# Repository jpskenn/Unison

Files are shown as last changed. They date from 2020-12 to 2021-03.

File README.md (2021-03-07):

# Unison / ユニゾン とは

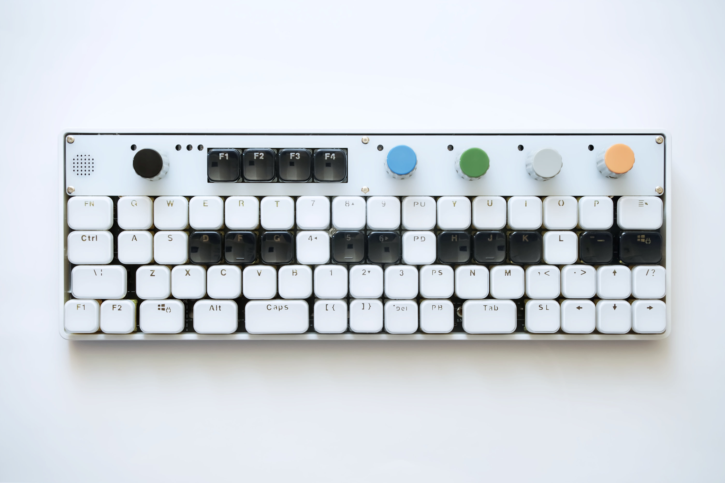
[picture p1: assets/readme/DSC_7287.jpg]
Unison Music style


ユニゾン（Unison）は、GH60互換の60%ケースに収まる狭ピッチキーボードです。  

ロータリーエンコーダを搭載しシーケンサーやMIDIキーボードとしてDAW連携を想定した”Misicスタイル（ミュージック・スタイル）”と、日常的なコンピュータ作業を想定した”Terminalスタイル（ターミナル・スタイル）”を用意しています。

音楽用とコンピュータ用のふたつのキーボードがひとつになるイメージから、音楽用語のユニゾンが名前の由来です。

## コンセプト

このキーボードのコンセプトや実現したい要件は次の通りです。

- 格好良いシンセサイザー、[OP-1](https://teenage.engineering/products/op-1)へのオマージュ。
- 狭ピッチなキーボードを作ってみたい。
- 狭ピッチなキーボードを使ってみたい。
- 挟ピッチなキーボードに触れる機会を増やしたい。
- ケースのあるキーボードを作りたいが、ケースの設計が大変だから、GH60型のケース対応にしてケース設計をメイン作業に含めない。
- キーキャップの選択肢を広げる。  
    安くて、そこそこ流通しているものが使えると普及しやすい。  
    標準的なキーキャプですべて埋められるレイアウトにしておく。
- 多キー、多ロータリーエンコーダ。

## 特徴

### 挟ピッチ

<!-- TODO　60%との比較写真  -->
<!-- TODO スイッチだけの写真 -->
通常の19.05mmのキーピッチに対して約87%となる、**縦16.4mm × 横16.8mm**のキーピッチを採用しています。

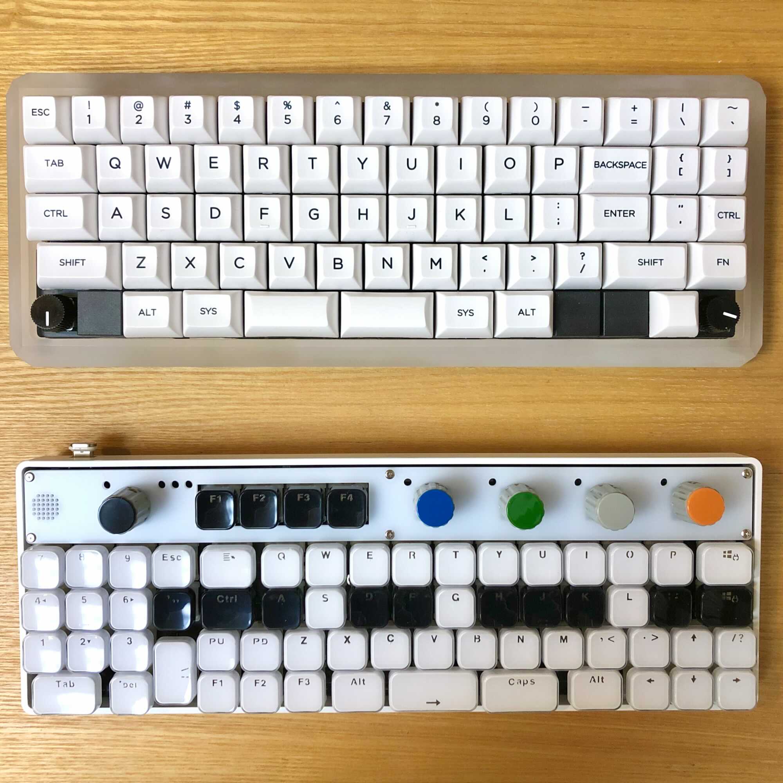
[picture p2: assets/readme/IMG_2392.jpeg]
通常のピッチの60%キーボードとの比較
  
通常のピッチの60%キーボードとの比較  
上：通常ピッチ Jones, 下：狭ピッチ Unison

デザインの元となったOP-1と同様に、4行×17列のキーとロータリーエンコーダが60%キーボードのケースに収まるように配置しました。  
また、キーピッチに少し余裕を持たせることで、入手性の良い”[Cherry MX Backlit Low Profile Keycap Set](https://yushakobo.jp/shop/cherry-mx-backlit-low-profile-keycap-set/)”が使用できるようにしています。

16mmピッチ＋α以下の挟ピッチ対応キーキャップが使用できます。  
挟ピッチ対応のキーキャップについては、e3w2q氏の記事”[狹ピッチ対応キーキャップを求めて](https://e3w2q.github.io/10/)”が大変参考になります。

<!-- TODO　ロープロキャップ写真 -->
<!-- TODO YKNキャップ写真 -->

### 独自の物理配列

以前設計した60%キーボードの[Jones](https://github.com/jpskenn/Jones)と同じく、2行目と3行目のずれをなくし、ロースタッガードとオルソリニアを組み合わせたキー配列を採用しています。  

アルファ部が左右対称になることで、肘、手首、指先が直線上に並んだ自然なポジションで打鍵できるなどのメリットがあります。  
詳しくは[Jones：キーレイアウト](https://github.com/jpskenn/Jones#キーレイアウト)を参照してください。

また、この配列を採用したことで、白鍵と黒鍵のずれをうまく表現できました。

### ふたつのレイアウト・スタイル

シーケンサーやMIDIキーボードとしてDAW連携を想定した”Misicスタイル”と、コンピュータでの作業を想定した”Terminalスタイル”の2種類が選べます。

#### Musicスタイル（ミュージック・スタイル）
<!-- TODO写真 -->

DAW連携を想定したMisicスタイルは、上部に5個のロータリーエンコーダと4個のスイッチを配置した、4行×17列のレイアウトです。

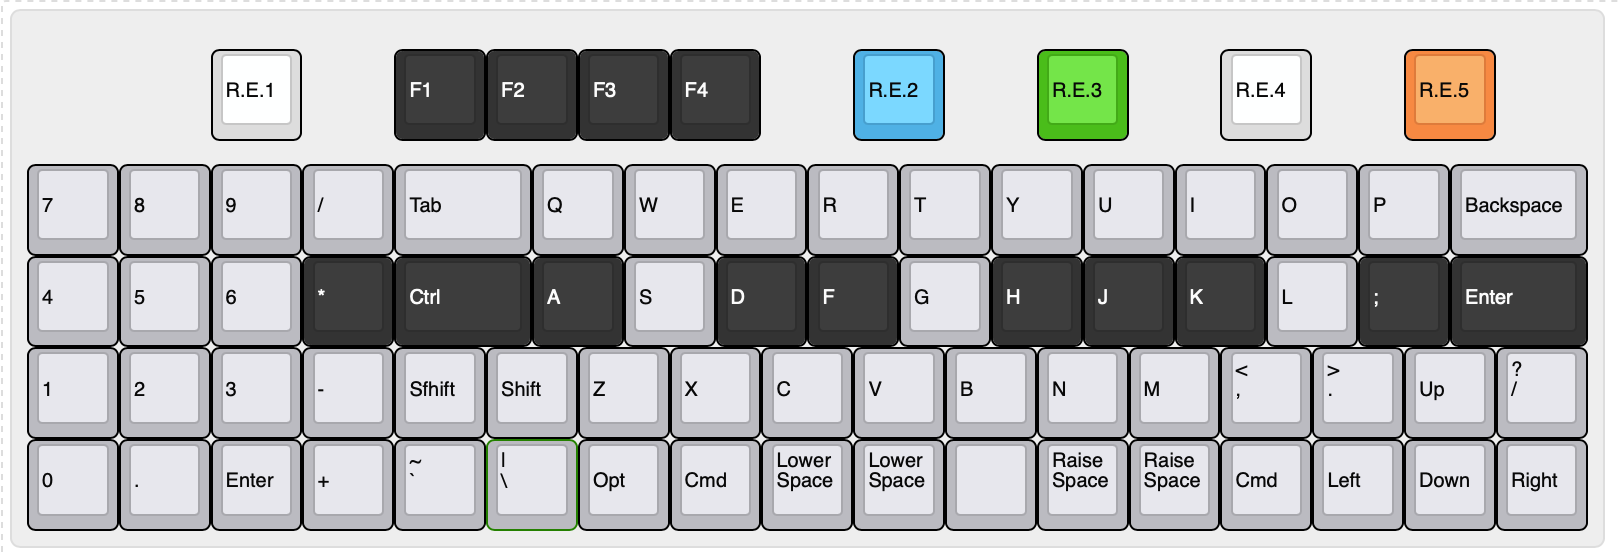
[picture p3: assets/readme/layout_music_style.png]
layout: Unison Music style
[Keyboard Layout Editor: Unison Music style](http://www.keyboard-layout-editor.com/#/gists/866c93c6eb4c580be0cf582207fa1836)

キーボードファームウェア[QMK](https://github.com/qmk/qmk_firmware)の機能によってシーケンサーとMIDIキーボードが使用でき、USB接続のMIDIデバイスとしてDAWと連携させることができます。  
もちろん、通常のコンピュータ用キーボードとしても使用できます。

シーケンサーは8トラック、32ステップあり、MIDIチャンネル1に固定されています。  
音源側（DAWなど）でチャンネル1にドラムセットを割り当てて使用するのが基本です。

MIDIキーボードは24鍵の鍵盤で演奏でき、ロータリーエンコーダを使ってベロシティやトランスポーズのコントロールやオクターブの上げ下げなどがおこなえます。

シーケンサーとMIDIキーボードは、それぞれ単独でも、両方を同時にでも使用できます。  
MIDIキーボードのチャンネルを変更することで、チャンネル1でシーケンサーを再生しながら、別チャンネルに割り当てた音源が演奏できます。

##### 参考

- シーケンサー操作ガイド
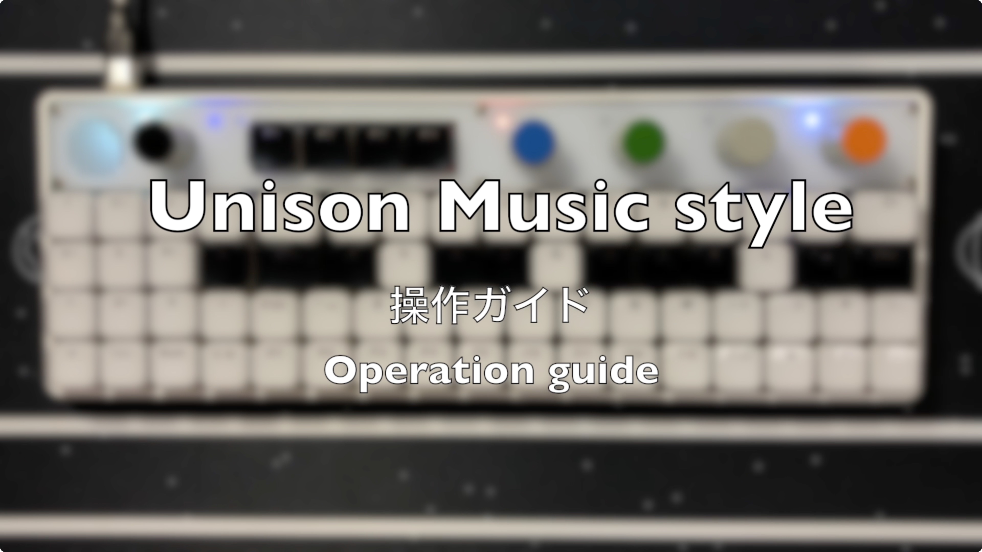
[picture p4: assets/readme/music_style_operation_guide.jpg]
Unison Music Style 操作ガイド / Operation guide (https://youtu.be/0ARp5gR2G88)
    
    [Unison Music Style 操作ガイド / Operation guide](https://youtu.be/0ARp5gR2G88)

- シーケンサーとMIDIキーボードを同時に使用するデモンストレーション  
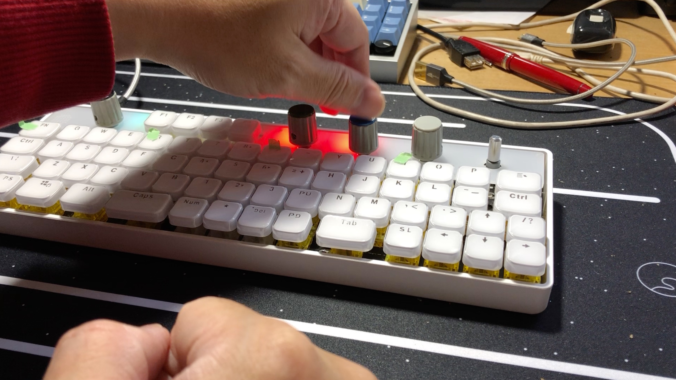
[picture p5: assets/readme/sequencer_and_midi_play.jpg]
QMK Sequencer & MIDI keyboard (http://www.youtube.com/watch?v=_A8NaXlWKeE "QMK Sequencer & MIDI keyboard")
      
    [QMK Sequencer & MIDI keyboard](http://www.youtube.com/watch?v=_A8NaXlWKeE)

#### Terminalスタイル（ターミナル・スタイル）
<!-- TODO写真 -->
コンピュータでの作業を想定したTerminalスタイルは、数字行を含めた5行×17列のレイアウトです。

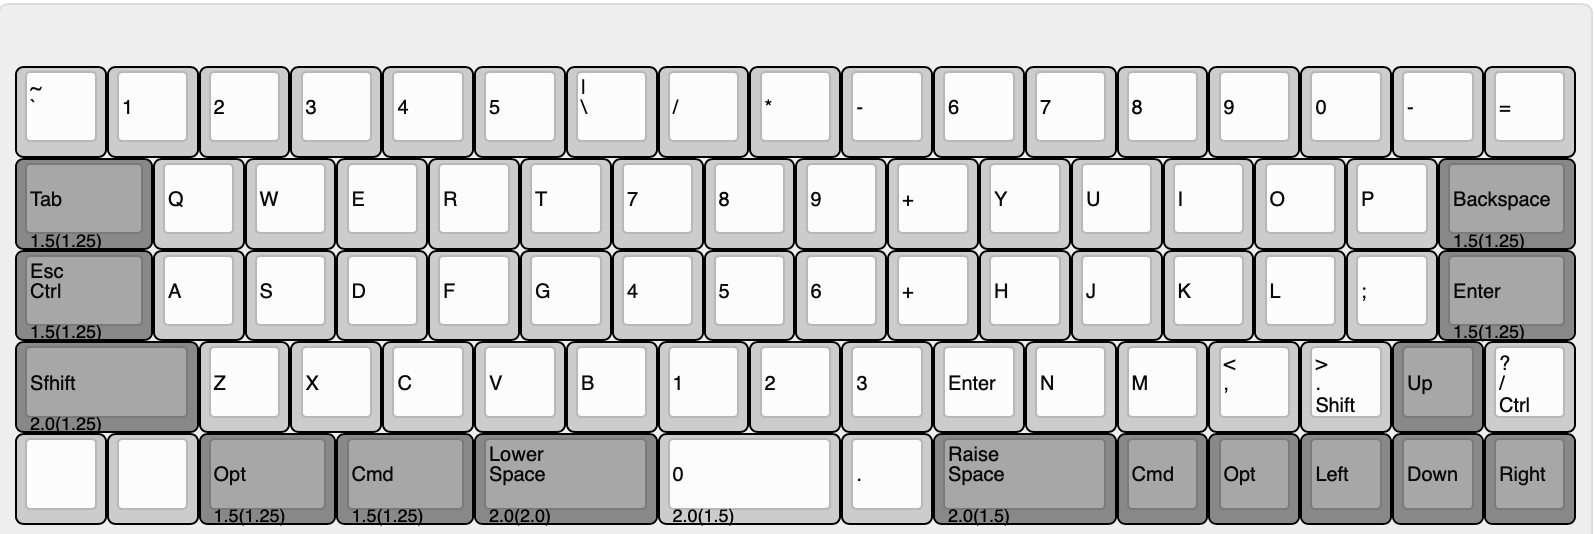
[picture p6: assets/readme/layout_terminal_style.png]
layout: Unison Music style
[Keyboard Layout Editor: Unison Terminal style](http://www.keyboard-layout-editor.com/#/gists/f8cf33730eca47e1e9039568cd3ca72c)

60%キーボードにテンキーを組み合わせたようなレイアウトで、挟ピッチによって手をホームポジションから大きく動かさずに入力することができ、コンピュータでの作業を快適におこなえます。  

最下行に配置した1.5uと2uのModキーの配置は、好みに応じていくつかのバリエーションから選択でき、全て1uにすることもできます。

テンキーは、肩を開いたホームポジションとなる中央への配置がおすすめですが、左や右に配置することもできます。  

また、スピーカーを搭載することで、特定のキー操作でメロディーを鳴らしたり、ピコピコという電子音とともにキー入力することもできます。  
音楽モードをONにすればキーボードを鍵盤に見立てて演奏することもでき、ちょっとしたハーモニーも楽しめます。

Terminalスタイルは、[VIA](https://caniusevia.com)または[Remap](https://remap-keys.app)によるキーマップの書き換えに対応しています。

## ビルドガイド

- [v04](https://github.com/jpskenn/Unison/blob/main/docs/BuildGuide_v04_JA.md)

## ギャラリー

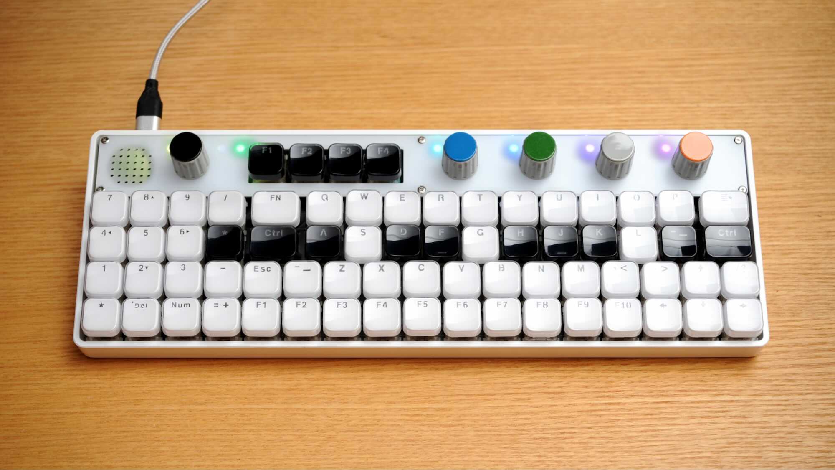
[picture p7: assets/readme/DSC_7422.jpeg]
Musicスタイル
  
Musicスタイル  
60% プラスチックケース ホワイト,  
Cherry MX Backlit Low Profile Keycap Set 白 & 黒,  
Bourns PEC11R 4115 w/K-100-16RS-GY and caps

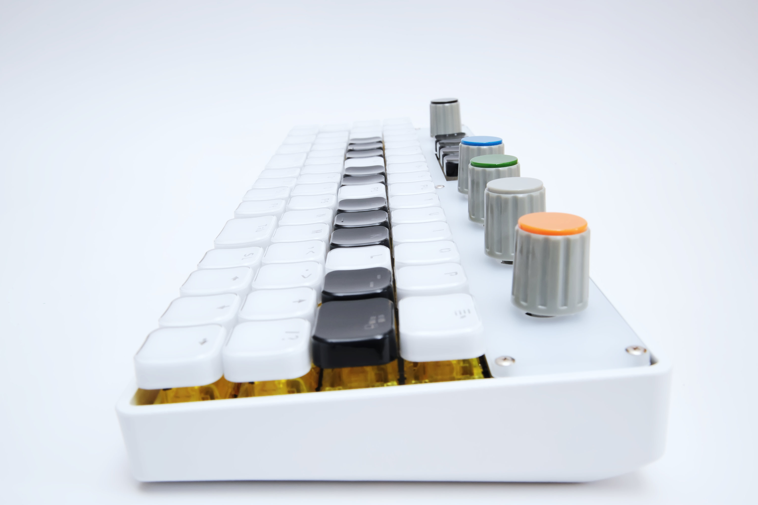
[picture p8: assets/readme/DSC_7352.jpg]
Musicスタイル, サイドビュー
  
Musicスタイル, サイドビュー  
60% プラスチックケース ホワイト,  
Cherry MX Backlit Low Profile Keycap Set 白 & 黒,  
EC11E18244AU w/K-100-16RS-GY and caps

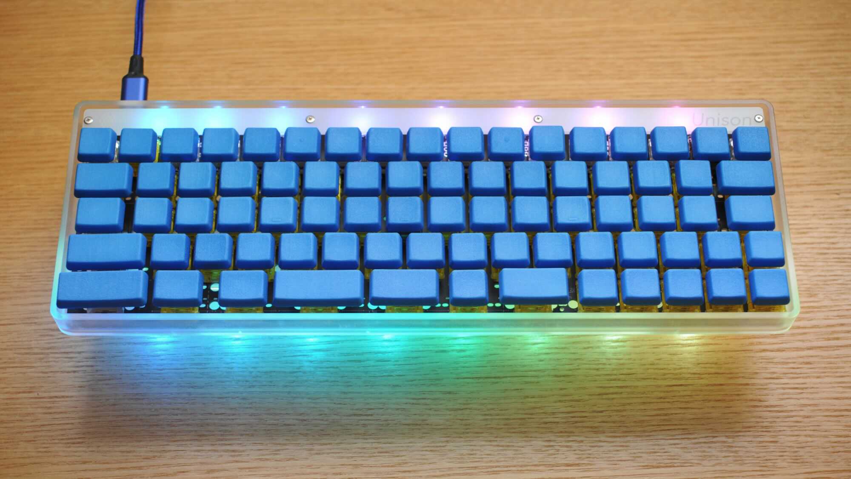
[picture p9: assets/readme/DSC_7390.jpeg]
  
Terminalスタイル, アンダーグローLED追加  
60% プラスチックケース クリア,  
YKNキーキャップセット(MX/ChocV2スイッチ 16x16mmキーピッチ用) v1.2 ナイロン・ブルー（磨き）

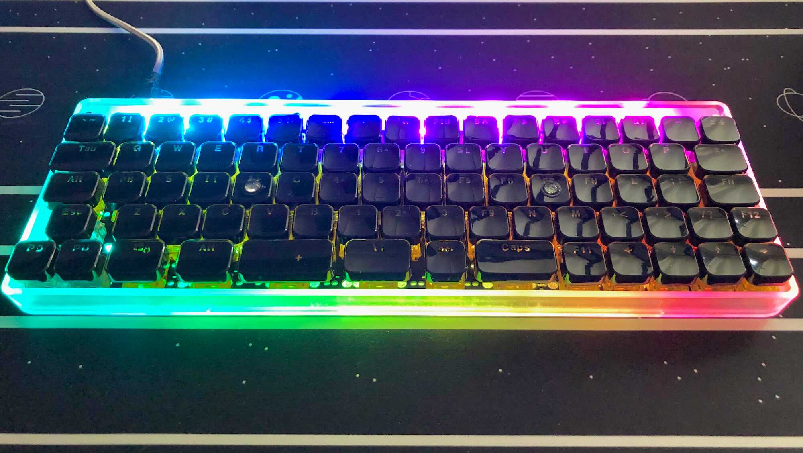
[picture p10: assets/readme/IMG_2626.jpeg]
  
Terminalスタイル, アンダーグローLED追加  
60% プラスチックケース クリア,  
Cherry MX Backlit Low Profile Keycap Set 黒

## 製作歴

### v05（開発中）

組み立てやすさの向上。  
細部の調整。

### v04

v03の不具合修正、各部調整などをおこなった、*ほぼ*完成版。  
ロータリーエンコーダを搭載せず、数字キーを含めた5行レイアウトのTerminalスタイルに対応。

簡易ケースレスなボトムプレートを用意したが、組み立てに難ありでボツ。

v04

### v03

初期動作版。

各部のサイズ調整をおこない、一通りの組み立てができ、動作も確認できた。  
キーピッチは縦16.4mm × 横16.8mmで確定。

LED光をマスクするミドルプレートや、アクリルのトッププレートも作成し、製品としての見た目もできあがってきた。  

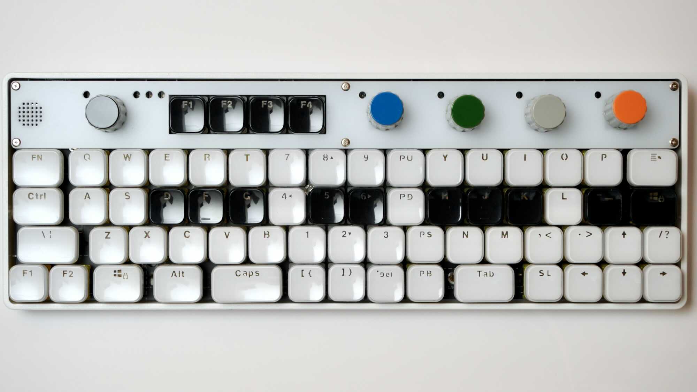
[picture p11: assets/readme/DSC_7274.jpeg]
v03


### v02

v01発注後、縦16mmピッチで基板データを仮に作成したもの。

キーピッチに余裕がないため、ボツ。

### v01

挟ピッチキーボードの試作として、Jonesの設計をベースに開発を開始。  
部品を手はんだするつもりで基板を発注したが、MCUのフットプリント間違いで組み立てられなかったたため、モックアップとして使用。

現在よりもピッチをつめた、5行×17列にロータリーエンコーダの1列を合わせたレイアウトで、縦のピッチは16mm未満。  
キーキャップの干渉具合や、ロータリーエンコーダの配置など、各部の寸法チェックをおこなった。

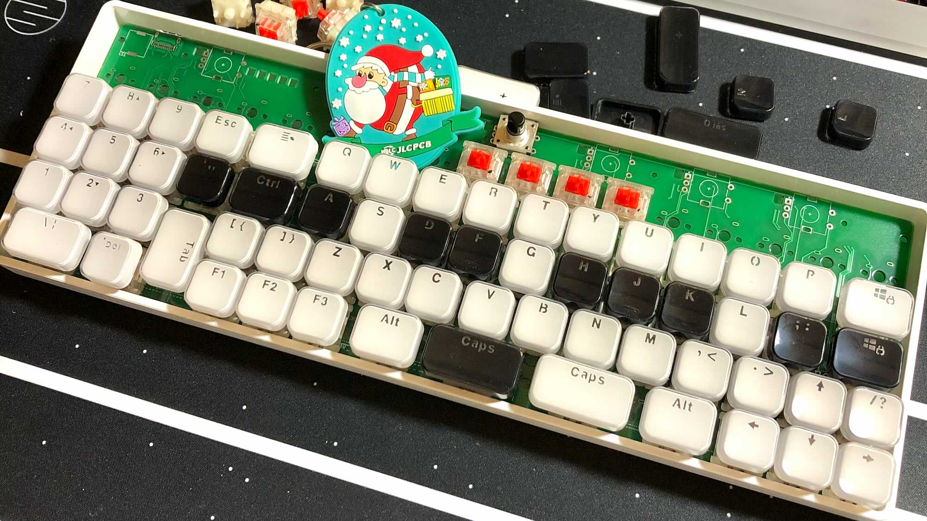
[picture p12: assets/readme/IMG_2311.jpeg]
v01


### v01以前

OP-1のスタイルに惚れ、60%キーボードの[Jones](https://github.com/jpskenn/Jones)に多数のロータリーエンコーダを搭載したバリエーションとして開発をスタート。

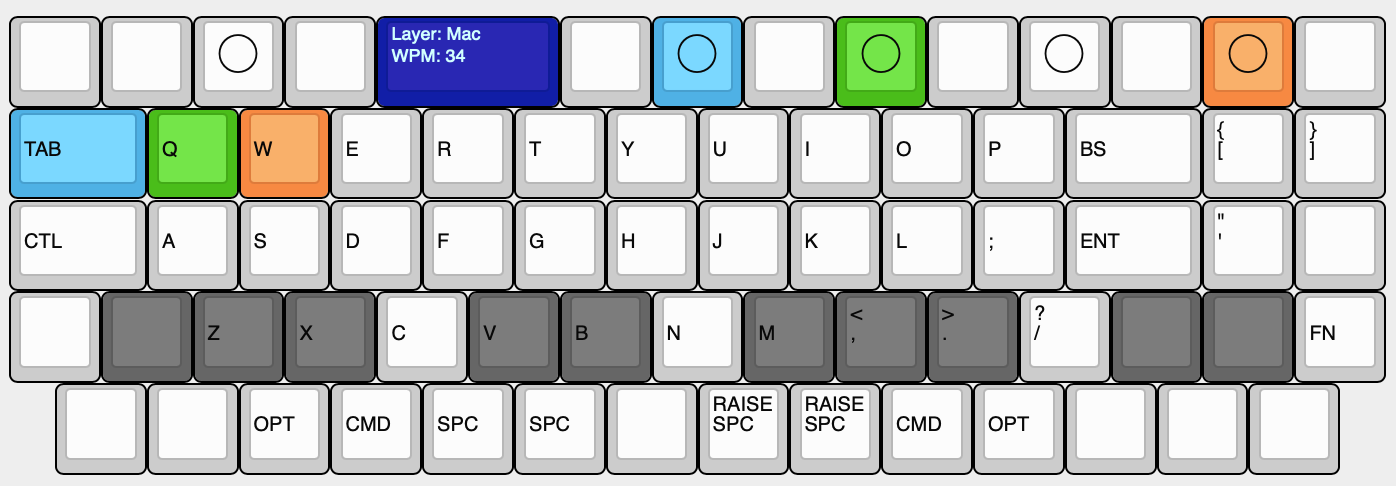
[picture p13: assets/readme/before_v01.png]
befre v01


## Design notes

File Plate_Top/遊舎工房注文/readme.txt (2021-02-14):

MacにてAffinity Designerを使いSVGファイルをを作成しました。
指定できる最小の線幅、0.1ptで作成しています。

A4サイズ内に、以下のパーツを配置しています。
285mm * 12.1mm　5個
285mm * 28.5mm　4個

同じ内容のPDFも用意しています。
緑（0, 255, 0)でA4の枠をつけてあります。

どちらか都合の良い方を使ってください。

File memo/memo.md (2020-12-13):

# Unisonについてのあれこれ

## サイズ、キー数

- Narrow pitch
    6 rows, 17 columns

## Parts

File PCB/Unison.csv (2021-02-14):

Comment | Designator | Footprint | LCSC
10uF | C1 | Capacitor_SMD:C_0805_2012Metric_Pad1.18x1.45mm_HandSolder | C15850
22pF | C2,C3 | Capacitor_SMD:C_0805_2012Metric_Pad1.18x1.45mm_HandSolder | C1804
0.1uF | C4,C5,C7 | Capacitor_SMD:C_0805_2012Metric_Pad1.18x1.45mm_HandSolder | C49678
1uF | C6 | Capacitor_SMD:C_0805_2012Metric_Pad1.18x1.45mm_HandSolder | C28323
PRTR5V0U2X | D102 | Package_TO_SOT_SMD:SOT-143
D | D1,D2,D3,D4,D5,D6,D7,D9,D10,D11,D12,D13,D14,D15,D16,D17,D18,D19,D20,D21,D22,D23,D24,D25,D26,D27,D28,D29,D30,D31,D32,D33,D34,D35,D36,D37,D38,D39,D40,D41,D42,D43,D44,D45,D46,D47,D48,D49,D50,D51,D52,D54,D55,D56,D57,D58,D59,D60,D61,D62,D63,D64,D66,D67,D68,D69,D70,D71,D72,D73,D74,D75,D76,D78,D79,D80,D81,D82,D83,D84,D85,D86,D87,D88,D90,D91,D92,D93,D94,D95,D96,D97,D98,D99 | Diode_SMD:D_SOD-123 | C81598
500mA | F1 | Fuse:Fuse_1206_3216Metric_Pad1.42x1.75mm_HandSolder
MountingHole | H1,H2,H3,H4,H5,H6,H7,H8,H9,H10,H11,H12,H13,H14,H15,H16,H17,H18 | ukiha:M2_Hole
USB4085-GF-A_REVA | J1 | USB4085:GCT_USB4085-GF-A_REVA
Conn_02x05[3_Odd_Even | J2 | Connector_PinHeader_2.54mm:PinHeader_2x03_P2.54mm_Vertical
LED Shade | J3 | Connector_PinSocket_2.54mm:PinSocket_1x03_P2.54mm_Vertical
Conn_01x02 | J4 | Connector_PinHeader_2.54mm:PinHeader_1x02_P2.54mm_Vertical
SolderJumper_3_Open | JP_LED1,JP_LED2 | Jumper:SolderJumper-3_P1.3mm_Open_Pad1.0x1.5mm_NumberLabels
SK6812MINI | L1,L2,L3,L4,L5,L6,L7,L8,L9 | LED_SMD:LED_SK6812MINI_PLCC4_3.5x3.5mm_P1.75mm
SERIAL_LED_TAPE | L15 | ukiha:StripLED_rev3
Speaker | LS1 | Buzzer_Beeper:Buzzer_Murata_PKMCS0909E4000-R1
1k | R1 | Resistor_SMD:R_0805_2012Metric_Pad1.20x1.40mm_HandSolder | C17513
10k | R4,R9 | Resistor_SMD:R_0805_2012Metric_Pad1.20x1.40mm_HandSolder | C17414
5.1k | R5,R6 | Resistor_SMD:R_0805_2012Metric_Pad1.20x1.40mm_HandSolder | C27834
22 | R7,R8 | Resistor_SMD:R_0805_2012Metric_Pad1.20x1.40mm_HandSolder | C17561
5.2x5.2mm | ResetSW1 | Button_Switch_SMD:SW_SPST_SKQG_WithStem
SW_Push | SW_21,SW_53,SW_8_1,SW_91,SW_18_1 | ukiha:MXOnly-1U-NoLED_16mm
SW_Push | SW_25_2,SW_60_2,SW_90_2 | ukiha:CherryMX_MidHeight_16mm_rev2_merged_hole_2U_vertical_guide
SW_Push | SW_6,SW_9,SW_14,SW_15,SW_16,SW_26,SW_29,SW_31,SW_34,SW_42,SW_43,SW_47,SW_48,SW_49,SW_50,SW_52,SW_54,SW_56,SW_57,SW_58,SW_59,SW_61,SW_62,SW_63,SW_64,SW_67,SW_68,SW_69,SW_71,SW_7_1,SW_74,SW_76,SW_79,SW_81,SW_84,SW_86,SW_89,SW_94,SW_95,SW_96,SW_10_1,SW_12_1,SW_12_2,SW_13_1,SW_13_2,SW_17_1,SW_19_1,SW_20_1,SW_23_1,SW_23_2,SW_24_1,SW_25_1,SW_27_1,SW_27_2,SW_28_1,SW_28_2,SW_30_1,SW_32_1,SW_32_2,SW_36_1,SW_36_2,SW_37_1,SW_38_1,SW_39_1,SW_40_1,SW_41_1,SW_41_2,SW_46_1,SW_46_2,SW_51_1,SW_51_2,SW_60_1,SW_70_1,SW_72_1,SW_73_1,SW_78_1,SW_78_2,SW_80_1,SW_82_1,SW_82_2,SW_83_1,SW_83_2,SW_85_1,SW_87_1,SW_87_2,SW_90_1,SW_97_1,SW_97_2,SW_98_1,SW_98_2 | ukiha:CherryMX_MidHeight_16mm_rev2_merged_hole
SW_Push | SW_10_2,SW_19_2,SW_35_1,SW_35_2,SW_39_2,SW_45_1,SW_45_2,SW_65_1,SW_75_3,SW_85_2 | ukiha:CherryMX_MidHeight_16mm_rev2_merged_hole_2u_guide
SW_Push | SW_37_2 | ukiha:CherryMX_MidHeight_16mm_rev2_merged_hole_1.5u_alt_guide
SW_Push | SW_60_3,SW_75_1 | ukiha:MXOnly-2U-NoLED_16mm
SW_Push | SW_75_2 | ukiha:MXOnly-1.5U-NoLED_16mm
SW_Push | SW_7_2,SW_8_2,SW_17_2,SW_18_2,SW_20_2,SW_25_3,SW_30_2,SW_35_3,SW_38_2,SW_45_3,SW_45_4,SW_65_2,SW_65_3,SW_70_2,SW_72_2,SW_73_2,SW_80_2,SW_85_3 | ukiha:CherryMX_MidHeight_16mm_rev2_merged_hole_1.5u_guide
Rotary_Encoder_Switch | SW_RE1,SW_RE2,SW_RE3,SW_RE4,SW_RE5 | ukiha:RotaryEncoder_Alps_EC11K-Switch_Vertical_H20mm
ATmega32U4-MU | U1 | swanmatch:QFN-44-1EP_7x7mm_Pitch0.5mm | C45874
16MHz | Y1 | Crystal:Crystal_SMD_3225-4Pin_3.2x2.5mm_HandSoldering | C13738

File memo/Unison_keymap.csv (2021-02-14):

XXXXXXX | XXXXXXX |  | KC_MUTE |  | XXXXXXX |  | KC_1 |  | KC_2 |  | KC_3 |  | KC_4 |  | XXXXXXX |  | KC_MUTE |  | XXXXXXX |  | KC_MUTE |  | XXXXXXX |  | KC_MUTE |  | XXXXXXX |  | KC_MUTE |  | XXXXXXX
KC_TAB |  | KC_Q |  | KC_W |  | KC_E |  | KC_R |  | KC_T |  | ESC |  | KC_PSLS |  | KC_PAST |  | KC_PMNS |  | KC_Y |  | KC_U |  | KC_I |  | KC_O |  | KC_P |  | KC_BSPC
KC_LCTL |  | KC_A |  | KC_S |  | KC_D |  | KC_F |  | KC_G |  | KC_P7 |  | KC_P8 |  | KC_P9 |  | KC_PPLS |  | KC_H |  | KC_J |  | KC_K |  | KC_L |  | KC_MINS |  | KC_ENT
KC_LSFT | KC_LSFT |  | KC_Z |  | KC_X |  | KC_C |  | KC_V |  | KC_B |  | KC_P1 |  | KC_P2 |  | KC_P3 |  | KC_PENT |  | KC_N |  | KC_M |  | KC_COMM |  | KC_DOT |  | KC_UP |  | SFT_SLS
KC_CAPS | KC_CAPS |  | OPT_L2 |  | XXXXXXX |  | CMD_L1 |  | SP_LOW |  | SP_LOW |  | KC_P0 |  | KC_P0 |  | KC_PDOT |  | SP_RAI |  | SP_RAI |  | SP_RAI |  | KC_RCTL |  | KC_LEFT |  | KC_DOWN |  | KC_RGHT
XXXXXXX | XXXXXXX |  | _______ |  | XXXXXXX |  | _______ |  | _______ |  | _______ |  | _______ |  | XXXXXXX |  | _______ |  | XXXXXXX |  | _______ |  | XXXXXXX |  | _______ |  | XXXXXXX |  | _______ |  | XXXXXXX
ESC |  | ! |  | @ |  | # |  | $ |  | % |  | _______ |  | _______ |  | _______ |  | _______ |  | ^ |  | & |  | * |  | ( |  | ) |  | DEL
_______ |  | _______ |  | _______ |  | _______ |  | _______ |  | _______ |  | _______ |  | _______ |  | _______ |  | _______ |  | `~ |  | -_ |  | =+ |  | [{ |  | ]} |  | \
_______ | _______ |  | M_PSCR |  | KC_SLCK |  | KC_PAUS |  | _______ |  | _______ |  | _______ |  | _______ |  | _______ |  | _______ |  | ~ |  | _ |  | + |  | { |  | }
_______ | _______ |  | MENU |  | XXXXXXX |  | _______ |  | _______ |  | _______ |  | _______ |  | _______ |  | _______ |  | _______ |  | _______ |  | _______ |  | _______ |  | _______ |  | _______ |  | _______
 |  |  | *MENU don't work on Mac
XXXXXXX | XXXXXXX |  | _______ |  | XXXXXXX |  | _______ |  | _______ |  | _______ |  | _______ |  | XXXXXXX |  | _______ |  | XXXXXXX |  | _______ |  | XXXXXXX |  | _______ |  | XXXXXXX |  | _______ |  | XXXXXXX
ESC |  | 1 |  | 2 |  | 3 |  | 4 |  | 5 |  | _______ |  | _______ |  | _______ |  | _______ |  | 6 |  | 7 |  | 8 |  | 9 |  | 0 |  | DEL
_______ |  | F1 |  | F2 |  | F3 |  | F4 |  | F5 |  | _______ |  | _______ |  | _______ |  | _______ |  | ← |  | ↓ |  | ↑ |  | → |  | ;: |  | '"
_______ | _______ |  | F6 |  | F7 |  | F8 |  | F9 |  | F10 |  | _______ |  | _______ |  | _______ |  | _______ |  | Home |  | PgDn |  | PgUp |  | End |  | : |  | "
_______ | _______ |  | F11 |  | XXXXXXX |  | F12 |  | _______ |  | _______ |  | _______ |  | _______ |  | _______ |  | _______ |  | _______ |  | _______ |  | ESC |  | _______ |  | _______ |  | _______
XXXXXXX | XXXXXXX |  | _______ |  | XXXXXXX |  | _______ |  | _______ |  | _______ |  | _______ |  | XXXXXXX |  | _______ |  | XXXXXXX |  | _______ |  | XXXXXXX |  | _______ |  | XXXXXXX |  | _______ |  | XXXXXXX
_______ |  | MAC |  | WIN |  | MIDI |  | RESET |  | _______ |  | _______ |  | _______ |  | _______ |  | _______ |  | RGB_HUI |  | RGB_SAI |  | RBG_VAI |  | _______ |  | RGB_RMOD |  | _______
_______ |  | AU_TOG |  | CK_TOGG |  | MU_TOG |  | MU_MOD |  | _______ |  | _______ |  | _______ |  | _______ |  | _______ |  | RBG_HUD |  | RBG_SAD |  | RBG_VAD |  | RGB_TOG |  | RGB_MOD |  | _______
_______ | _______ |  | CK_RST |  | CK_DOWN |  | CK_UP |  | _______ |  | _______ |  | _______ |  | _______ |  | _______ |  | _______ |  | _______ |  | _______ |  | _______ |  | _______ |  | _______ |  | _______
_______ | _______ |  | _______ |  | XXXXXXX |  | _______ |  | _______ |  | _______ |  | _______ |  | _______ |  | _______ |  | _______ |  | _______ |  | _______ |  | _______ |  | _______ |  | _______ |  | _______

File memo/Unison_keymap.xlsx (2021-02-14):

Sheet: Sheet1
MAC
 | XXXXXXX | XXXXXXX | KC_MUTE | XXXXXXX | KC_P1 | KC_P2 | KC_P3 | KC_P4 | XXXXXXX | KC_MUTE | XXXXXXX | KC_MUTE | XXXXXXX | KC_MUTE | XXXXXXX | KC_MUTE | XXXXXXX
 | KC_TAB |  | KC_Q | KC_W | KC_E | KC_R | KC_T | KC_LBRC | KC_GRV | KC_BSLS | KC_RBRC | KC_Y | KC_U | KC_I | KC_O | KC_P | KC_BSPC
 | KC_LCTL |  | KC_A | KC_S | KC_D | KC_F | KC_G | KC_SCLN | KC_NLCK | KC_ESC | KC_QUOT | KC_H | KC_J | KC_K | KC_L | KC_MINS | KC_ENT
 | KC_LSFT | KC_LSFT | KC_Z | KC_X | KC_C | KC_V | KC_B | M_PSCR | KC_INS | KC_HOME | XXXXXXX | KC_N | KC_M | KC_COMM | KC_DOT | KC_UP | SFT_SLS
 | KC_CAPS | KC_CAPS | KC_LALT | XXXXXXX | KC_LGUI | SP_LOW | SP_LOW | KC_P0 | KC_DEL | KC_END | KC_PENT | SP_RAI | SP_RAI | KC_RCTL | KC_LEFT | KC_DOWN | KC_RGHT
LOWER
 | XXXXXXX |  | _______ | _______ | XXXXXXX | _______ | _______ | _______ | _______ | XXXXXXX | _______ | XXXXXXX | _______ | XXXXXXX | _______ | XXXXXXX | _______ | XXXXXXX
 | KC_1 |  | KC_2 | KC_3 | KC_4 | KC_5 | KC_6 | _______ | _______ | _______ | _______ | KC_7 | KC_8 | KC_9 | KC_0 | KC_MINS | KC_EQL
 | KC_F1 |  | KC_F2 | KC_F3 | KC_F4 | KC_F5 | KC_F6 | _______ | _______ | _______ | _______ | KC_F7 | KC_F8 | KC_F9 | KC_F10 | KC_F11 | KC_F12
 | _______ |  | _______ | _______ | _______ | _______ | _______ | _______ | _______ | _______ | _______ | _______ | _______ | _______ | KC_LBRC | KC_RBRC | KC_PGUP | _______
 | _______ |  | _______ | _______ | _______ | _______ | _______ | _______ | _______ | _______ | _______ | _______ | _______ | _______ | _______ | KC_HOME | KC_PGDN | KC_END
RAISE
 | XXXXXXX |  | _______ | _______ | XXXXXXX | _______ | _______ | _______ | _______ | XXXXXXX | _______ | XXXXXXX | _______ | XXXXXXX | _______ | XXXXXXX | _______ | XXXXXXX
 | KC_EXLM |  | KC_AT | KC_HASH | KC_DLR | KC_PERC | KC_CIRC | _______ | _______ | _______ | _______ | KC_AMPR | KC_ASTR | KC_LPRN | KC_RPRN | KC_UNDS | KC_PLUS
 | _______ |  | _______ | _______ | _______ | _______ | KC_ESC | _______ | _______ | _______ | _______ | KC_LEFT | KC_DOWN | KC_UP | KC_RGHT | KC_SCLN | KC_DEL
 | _______ |  | _______ | _______ | _______ | _______ | _______ | _______ | _______ | _______ | _______ | _______ | _______ | _______ | KC_LCBR | KC_RCBR | KC_PGUP | _______
 | _______ |  | _______ | _______ | _______ | _______ | _______ | _______ | _______ | _______ | _______ | _______ | _______ | _______ | _______ | KC_HOME | KC_PGDN | KC_END
ADJUST
 | XXXXXXX |  | _______ | _______ | XXXXXXX | _______ | _______ | _______ | _______ | XXXXXXX | _______ | XXXXXXX | _______ | XXXXXXX | _______ | XXXXXXX | _______ | XXXXXXX
 | _______ |  | MIDI | WIN | _______ | RESET | _______ | _______ | _______ | _______ | _______ | RGB_HUI | RGB_SAI | RGB_VAI | _______ | RGB_RMOD | _______
 | _______ |  | _______ | _______ | _______ | _______ | _______ | _______ | _______ | _______ | _______ | RGB_HUD | RGB_SAD | RGB_VAD | RGB_TOG | RGB_MOD | _______
 | _______ |  | _______ | _______ | _______ | _______ | _______ | _______ | _______ | _______ | _______ | _______ | NUM | MAC | _______ | _______ | _______ | _______
 | _______ |  | _______ | _______ | _______ | _______ | _______ | _______ | _______ | _______ | _______ | _______ | _______ | _______ | _______ | _______ | _______ | _______

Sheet: Sheet1 (2)
MAC
 | XXXXXXX | XXXXXXX | KC_MUTE | XXXXXXX | KC_P1 | KC_P2 | KC_P3 | KC_P4 | XXXXXXX | KC_MUTE | XXXXXXX | KC_MUTE | XXXXXXX | KC_MUTE | XXXXXXX | KC_MUTE | XXXXXXX
 | KC_TAB |  | KC_Q | KC_W | KC_E | KC_R | KC_T | KC_LBRC | KC_GRV | KC_BSLS | KC_RBRC | KC_Y | KC_U | KC_I | KC_O | KC_P | KC_BSPC
 | KC_LCTL |  | KC_A | KC_S | KC_D | KC_F | KC_G | KC_SCLN | KC_NLCK | KC_ESC | KC_QUOT | KC_H | KC_J | KC_K | KC_L | KC_MINS | KC_ENT
 | KC_LSFT | KC_LSFT | KC_Z | KC_X | KC_C | KC_V | KC_B | M_PSCR | KC_INS | KC_HOME | XXXXXXX | KC_N | KC_M | KC_COMM | KC_DOT | KC_UP | SFT_SLS
 | KC_CAPS | KC_CAPS | KC_LALT | XXXXXXX | KC_LGUI | SP_LOW | SP_LOW | KC_P0 | KC_DEL | KC_END | KC_PENT | SP_RAI | SP_RAI | KC_RCTL | KC_LEFT | KC_DOWN | KC_RGHT
LOWER
 | XXXXXXX |  | _______ | _______ | XXXXXXX | _______ | _______ | _______ | _______ | XXXXXXX | _______ | XXXXXXX | _______ | XXXXXXX | _______ | XXXXXXX | _______ | XXXXXXX
 | KC_1 |  | KC_2 | KC_3 | KC_4 | KC_5 | KC_6 | _______ | _______ | _______ | _______ | KC_7 | KC_8 | KC_9 | KC_0 | KC_MINS | KC_EQL
 | KC_F1 |  | KC_F2 | KC_F3 | KC_F4 | KC_F5 | KC_F6 | _______ | _______ | _______ | _______ | KC_F7 | KC_F8 | KC_F9 | KC_F10 | KC_F11 | KC_F12
 | _______ |  | _______ | _______ | _______ | _______ | _______ | _______ | _______ | _______ | _______ | _______ | _______ | _______ | KC_LBRC | KC_RBRC | KC_PGUP | _______
 | _______ |  | _______ | _______ | _______ | _______ | _______ | _______ | _______ | _______ | _______ | _______ | _______ | _______ | _______ | KC_HOME | KC_PGDN | KC_END
RAISE
 | XXXXXXX |  | _______ | _______ | XXXXXXX | _______ | _______ | _______ | _______ | XXXXXXX | _______ | XXXXXXX | _______ | XXXXXXX | _______ | XXXXXXX | _______ | XXXXXXX
 | KC_EXLM |  | KC_AT | KC_HASH | KC_DLR | KC_PERC | KC_CIRC | _______ | _______ | _______ | _______ | KC_AMPR | KC_ASTR | KC_LPRN | KC_RPRN | KC_UNDS | KC_PLUS
 | _______ |  | _______ | _______ | _______ | _______ | KC_ESC | _______ | _______ | _______ | _______ | KC_LEFT | KC_DOWN | KC_UP | KC_RGHT | KC_SCLN | KC_DEL
 | _______ |  | _______ | _______ | _______ | _______ | _______ | _______ | _______ | _______ | _______ | _______ | _______ | _______ | KC_LCBR | KC_RCBR | KC_PGUP | _______
 | _______ |  | _______ | _______ | _______ | _______ | _______ | _______ | _______ | _______ | _______ | _______ | _______ | _______ | _______ | KC_HOME | KC_PGDN | KC_END
ADJUST
 | XXXXXXX |  | _______ | _______ | XXXXXXX | _______ | _______ | _______ | _______ | XXXXXXX | _______ | XXXXXXX | _______ | XXXXXXX | _______ | XXXXXXX | _______ | XXXXXXX
 | _______ |  | MIDI | WIN | _______ | RESET | _______ | _______ | _______ | _______ | _______ | RGB_HUI | RGB_SAI | RGB_VAI | _______ | RGB_RMOD | _______
 | _______ |  | _______ | _______ | _______ | _______ | _______ | _______ | _______ | _______ | _______ | RGB_HUD | RGB_SAD | RGB_VAD | RGB_TOG | RGB_MOD | _______
 | _______ |  | _______ | _______ | _______ | _______ | _______ | _______ | _______ | _______ | _______ | _______ | NUM | MAC | _______ | _______ | _______ | _______
 | _______ |  | _______ | _______ | _______ | _______ | _______ | _______ | _______ | _______ | _______ | _______ | _______ | _______ | _______ | _______ | _______ | _______

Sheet: Sheet3
XXXXXXX | XXXXXXX |  | KC_MUTE |  | XXXXXXX |  | KC_1 |  | KC_2 |  | KC_3 |  | KC_4 |  | XXXXXXX |  | KC_MUTE |  | XXXXXXX |  | KC_MUTE |  | XXXXXXX |  | KC_MUTE |  | XXXXXXX |  | KC_MUTE |  | XXXXXXX
KC_TAB |  | KC_Q |  | KC_W |  | KC_E |  | KC_R |  | KC_T |  | ESC |  | KC_PSLS |  | KC_PAST |  | KC_PMNS |  | KC_Y |  | KC_U |  | KC_I |  | KC_O |  | KC_P |  | KC_BSPC
KC_LCTL |  | KC_A |  | KC_S |  | KC_D |  | KC_F |  | KC_G |  | KC_P7 |  | KC_P8 |  | KC_P9 |  | KC_PPLS |  | KC_H |  | KC_J |  | KC_K |  | KC_L |  | KC_MINS |  | KC_ENT
KC_LSFT | KC_LSFT |  | KC_Z |  | KC_X |  | KC_C |  | KC_V |  | KC_B |  | KC_P1 |  | KC_P2 |  | KC_P3 |  | KC_PENT |  | KC_N |  | KC_M |  | KC_COMM |  | KC_DOT |  | KC_UP |  | SFT_SLS
KC_CAPS | KC_CAPS |  | OPT_L2 |  | XXXXXXX |  | CMD_L1 |  | SP_LOW |  | SP_LOW |  | KC_P0 |  | KC_P0 |  | KC_PDOT |  | SP_RAI |  | SP_RAI |  | SP_RAI |  | KC_RCTL |  | KC_LEFT |  | KC_DOWN |  | KC_RGHT
XXXXXXX | XXXXXXX |  | _______ |  | XXXXXXX |  | _______ |  | _______ |  | _______ |  | _______ |  | XXXXXXX |  | _______ |  | XXXXXXX |  | _______ |  | XXXXXXX |  | _______ |  | XXXXXXX |  | _______ |  | XXXXXXX
ESC |  | ! |  | @ |  | # |  | $ |  | % |  | _______ |  | _______ |  | _______ |  | _______ |  | ^ |  | & |  | * |  | ( |  | ) |  | DEL
_______ |  | _______ |  | _______ |  | _______ |  | _______ |  | _______ |  | _______ |  | _______ |  | _______ |  | _______ |  | `~ |  | -_ |  | =+ |  | [{ |  | ]} |  | \
_______ | _______ |  | M_PSCR |  | KC_SLCK |  | KC_PAUS |  | _______ |  | _______ |  | _______ |  | _______ |  | _______ |  | _______ |  | ~ |  | _ |  | + |  | { |  | }
_______ | _______ |  | MENU |  | XXXXXXX |  | _______ |  | _______ |  | _______ |  | _______ |  | _______ |  | _______ |  | _______ |  | _______ |  | _______ |  | _______ |  | _______ |  | _______ |  | _______
 |  |  | *MENU don't work on Mac
XXXXXXX | XXXXXXX |  | _______ |  | XXXXXXX |  | _______ |  | _______ |  | _______ |  | _______ |  | XXXXXXX |  | _______ |  | XXXXXXX |  | _______ |  | XXXXXXX |  | _______ |  | XXXXXXX |  | _______ |  | XXXXXXX
ESC |  | 1 |  | 2 |  | 3 |  | 4 |  | 5 |  | _______ |  | _______ |  | _______ |  | _______ |  | 6 |  | 7 |  | 8 |  | 9 |  | 0 |  | DEL
_______ |  | F1 |  | F2 |  | F3 |  | F4 |  | F5 |  | _______ |  | _______ |  | _______ |  | _______ |  | ← |  | ↓ |  | ↑ |  | → |  | ;: |  | '"
_______ | _______ |  | F6 |  | F7 |  | F8 |  | F9 |  | F10 |  | _______ |  | _______ |  | _______ |  | _______ |  | Home |  | PgDn |  | PgUp |  | End |  | : |  | "
_______ | _______ |  | F11 |  | XXXXXXX |  | F12 |  | _______ |  | _______ |  | _______ |  | _______ |  | _______ |  | _______ |  | _______ |  | _______ |  | ESC |  | _______ |  | _______ |  | _______
XXXXXXX | XXXXXXX |  | _______ |  | XXXXXXX |  | _______ |  | _______ |  | _______ |  | _______ |  | XXXXXXX |  | _______ |  | XXXXXXX |  | _______ |  | XXXXXXX |  | _______ |  | XXXXXXX |  | _______ |  | XXXXXXX
_______ |  | MAC |  | WIN |  | MIDI |  | RESET |  | _______ |  | _______ |  | _______ |  | _______ |  | _______ |  | RGB_HUI |  | RGB_SAI |  | RBG_VAI |  | _______ |  | RGB_RMOD |  | _______
_______ |  | AU_TOG |  | CK_TOGG |  | MU_TOG |  | MU_MOD |  | _______ |  | _______ |  | _______ |  | _______ |  | _______ |  | RBG_HUD |  | RBG_SAD |  | RBG_VAD |  | RGB_TOG |  | RGB_MOD |  | _______
_______ | _______ |  | CK_RST |  | CK_DOWN |  | CK_UP |  | _______ |  | _______ |  | _______ |  | _______ |  | _______ |  | _______ |  | _______ |  | _______ |  | _______ |  | _______ |  | _______ |  | _______
_______ | _______ |  | _______ |  | XXXXXXX |  | _______ |  | _______ |  | _______ |  | _______ |  | _______ |  | _______ |  | _______ |  | _______ |  | _______ |  | _______ |  | _______ |  | _______ |  | _______

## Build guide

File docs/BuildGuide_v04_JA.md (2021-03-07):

# Unison v04 ビルドガイド

購入していただいた方、リポジトリから製造していただいた方、その他の皆様、Unisonに興味を持っていただきありがとうございます。

Unisonのコンセプトや特徴などについては、[Unison README](https://github.com/jpskenn/Unison/blob/main/README.md)をご覧ください。

## 注意事項、制限など

- 5pinスイッチの取り付け穴が緩めです。（v04のみ）

    設計上の不備により、5pinスイッチをがっちりと取り付けできないため、スイッチが傾かないように注意して取り付けてください。

- 中央下側のネジは、ケースへ止めずに組み立てます。

    スイッチをしっかりと取り付けることを優先しています。  
    この箇所をケースへネジ止めしない場合でも、特に不具合は見受けられません。  

- 中央下側のネジ穴にかぶさるスイッチは、スイッチの足を加工して取り付けます。  

    該当箇所では、スイッチ取り付けの安定感が低下したり、打鍵感が悪くなることがあります。

- ネジ穴にかぶさるスイッチは、基板をケースへねじ止めした後、ソケットを介して取り付けます。

    はんだ付けしないため、スイッチが少しぐらつくことがあります。  
    また、**v04ではMill-Maxソケットを使用するため、はんだ付けの難易度が多少高め**です。

- スイッチを上下逆向きや、横向きに取り付ける箇所があります。  

    キーキャップによっては、キャップの内部構造とスイッチが当たるかもしれません。

- もしかしたら、取り付けできないケースがあるかもしれません。  

  現在のところ、下記のケースで取り付けできることを確認済みです。
  - [KBDfans TOFU 60% ALUMINUM CASE](https://kbdfans.com/products/kbdfans-tofu-60-aluminum-case)  
  - [KBDfans 5° FROSTED ACRYLIC CNC 60% CASE](https://kbdfans.com/products/pre-order-kbdfans5-transparent-acrylic-cnc-60-case)  
  - [60% プラスチックケース](https://yushakobo.jp/shop/60-plastic-case/)（簡単な加工が必要）

  上記以外のケースへの取り付けの成功／失敗の報告を募集しています。

- Musicスタイルのスピーカーホールは、デザイン上設けられたハリボテです。

    ファームウェアサイズの制限により、MIDI機能とスピーカーを使用するAudio機能は同時に有効化できません。  
    MIDI機能を使用しない場合は、Audio機能を有効化してスピーカーを使用できます。

- スピーカーを使用するAudio機能は、単音再生となります。（v04のみ）

    設計上の都合により、v04では2音同時再生に対応できませんでした。

## 部品リスト

このキットを組み立てるためには、”キット内容物”に加え、”別途用意が必要な部品”が必要です。  

なお、”オプション部品”は使いたい機能などに合わせて任意に用意してください。  

### キット内容物

- Unison v04 試作版
    | 部品名 | 個数 |
    | ----- | -----: |
    | Unison 基板 v04（部品実装済み） | 1 |
    | スペーサー 8mm | 6  |
    | ネジ M2 5mm<br>スペーサー固定用 | 6  |
    | ネジ 低頭 M2 6mm<br>プレート固定用 | 6  |
    | ネジ 低頭 M2 5mm<br>ケース固定用 | 5 |
    | Mill-Maxソケット 金色<br> [7305-0-15-15-47-27-10-0](https://www.digikey.jp/product-detail/ja/mill-max-manufacturing-corp/7305-0-15-15-47-27-10-0/ED1039-ND/1765737)| 10 |
    | Mill-Maxソケット 銀色<br>[0305-2-15-80-47-80-10-0](https://www.digikey.jp/product-detail/ja/mill-max-manufacturing-corp/0305-2-15-80-47-80-10-0/ED90584-ND/2639493)<br>（取り付け失敗時用予備）| 4 |

- プレート（レイアウト・スタイルに合わせていずれか一方）

  - Musicスタイル用 プレート
    | 部品名 | 個数 |
    | ----- | -----: |
    | Musicスタイル用トップレート（アクリル） | 1 |
    | Musicスタイル用ミドルプレート v04（FR-4） | 1 |

  - Terminalスタイル用 プレート
    | 部品名 | 個数 |
    | ----- | -----: |
    | Terminalスタイル用トップレート（アクリル） | 1 |

### 別途用意が必要な部品

- Musicスタイル、Terminalスタイル共通
    | 部品名 | 個数 |
    | ----- | -----: |
    | MXスイッチ<br>取り付けの安定性が高い、5pinのものを推奨。 | Musicスタイル：70<br>Terminalスタイル：最大 83 (\*) |
    | キーキャップ<br>挟ピッチに対応する、16mm＋α以下のもの。<br>[Cherry MX Backlit Low Profile Keycap Set](https://yushakobo.jp/shop/cherry-mx-backlit-low-profile-keycap-set/), [YKNキーキャップセット(MX/ChocV2スイッチ 16x16mmキーピッチ用) v1.2](https://make.dmm.com/item/1279617/)など | 同上 |
    | ケース<br>GH60型 | 1 |
    | USBケーブル <br>Type-C | 1 |

- Musicスタイル
    | 部品名 | 個数 |
    | ----- | -----: |
    | ロータリーエンコーダ<br>EC11, EC12, またはその互換品。<br>取り付け時に、基板表面から軸の先端までが20〜25mm程度のもの。<br>軸の直径が9mm以下のもの。（ALPSのセレーションモデルは非推奨）<br>[ALPS EC11E18244AU](https://tech.alpsalpine.com/prod/j/html/encoder/incremental/ec11/ec11e18244au.html), [BOURNS PEC11R-4015](https://www.digikey.jp/htmldatasheets/production/1399781/0/0/1/pec11r-4015f-n0024.html)など | 5 |
    | ロータリーエンコーダ用ノブ・つまみ | 5 |
    | LED<br>SK6812MINI<br>無くても動作するが、シーケンサーの操作などがほぼ不可能となる | 7 |

### オプション部品

| 部品名 | 個数 |
| ----- | -----: |
| LED<br>SK6812MINI | 最大 9 (\*) |
| LEDテープ<br>アンダーグロー用 26cm程度 | 1 |
| スピーカー<br>[Murata PKMCS0909E4000-R1](https://www.digikey.jp/product-detail/ja/PKMCS0909E4000-R1/490-9647-1-ND/4878401/?itemSeq=353128711) | 1 |

## 組み立てに必要な工具

ドライバー、ピンセット、はんだ付け関連用品など、一般的な電子工作向け工具を使用します。  
[遊舎工房の工具セット](https://yushakobo.jp/shop/a9900to/)を参考に用意してください。

なお、なくても組み立てはできますが、何か不具合があった場合の原因究明のために、テスターがあると便利です。

## キット内容物概要

- 基板おもて側  
部品が何も取り付けられていない方が、おもて側です。
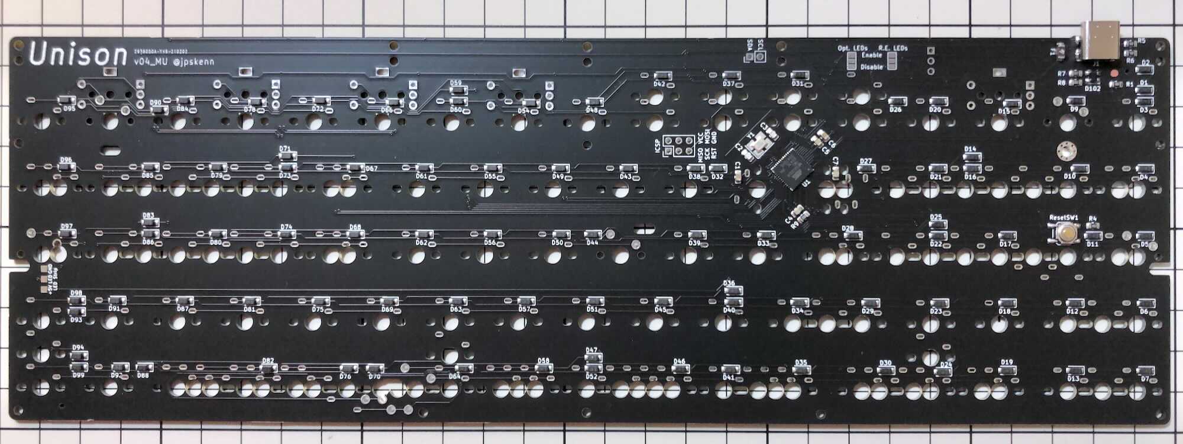
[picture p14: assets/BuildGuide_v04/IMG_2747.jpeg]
基板おもて側


- 基板裏側  
細かな部品がたくさん取り付けられている方が、裏側です。  
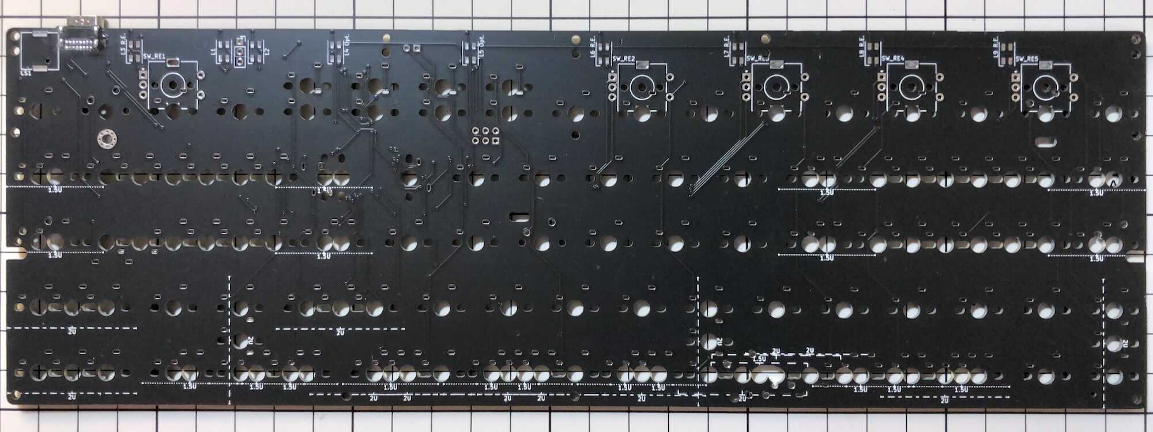
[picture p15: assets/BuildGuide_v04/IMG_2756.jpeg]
基板裏側


- プレート類  
    上から順に
    Terminalスタイル用トッププレートおもて側（保護用紙を剥がした状態）  
    Musicスタイル用トッププレート（保護用紙を剥がした状態）  
    Musicスタイル用ミドルプレートおもて側  
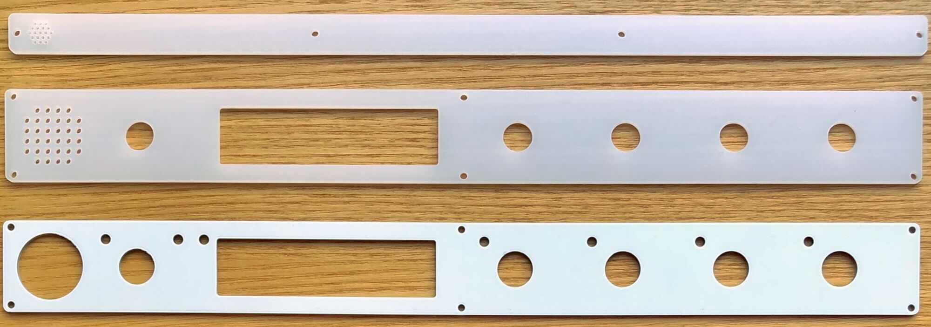
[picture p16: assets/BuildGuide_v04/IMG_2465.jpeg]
プレート類
    

- 小物パーツ類
    上段左より、スペーサー 8mm, ネジ M2 5mm, ネジ 低頭 M2 5mm, ネジ 低頭 M2 6mm。  
    下段左より、Mill-Maxソケット 金色, Mill-Maxソケット 銀色,  
    （※ネジ類の色は仕入れ時期などによって変わることがあります）
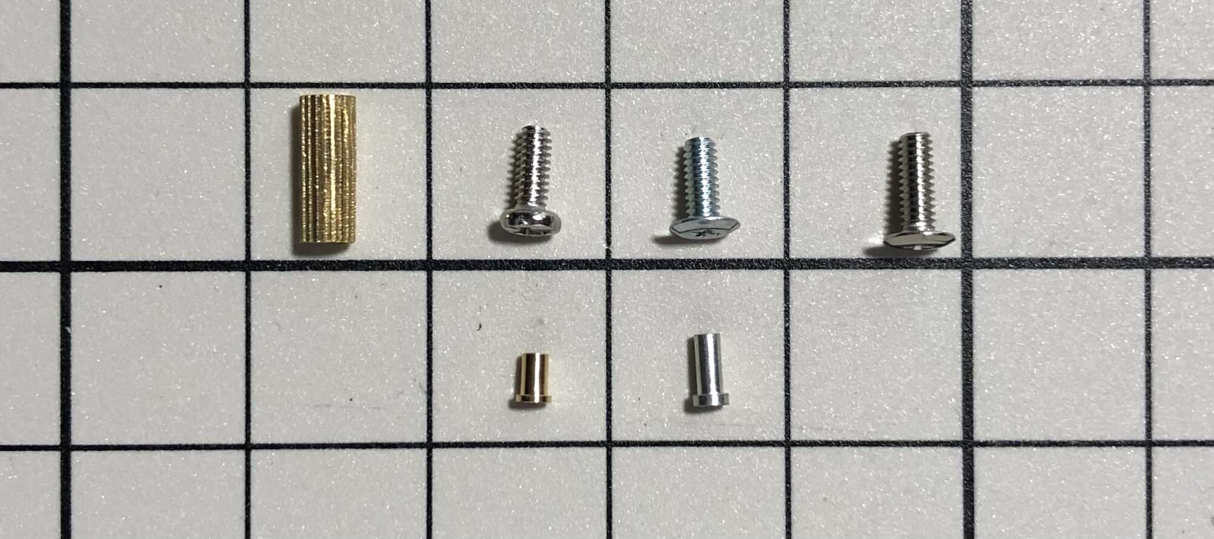
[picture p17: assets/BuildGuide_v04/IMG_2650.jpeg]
小物パーツ類
    

## 組み立て手順

**作業をおこなう前に、各手順に目を通しておくと作業ミスの防止につながります。**

### 組み立て前の確認

#### 同梱物の確認

組み立てを始める前に、同梱物に不足がないか確認してください。  
また、基板に破損がないか、実装された部品が外れていないか（梱包の中に小さな部品が落ちていないか）も確認してください。

#### 接続確認

続いて、基板をPCやMacに接続して、キーボードとして認識されるかを確認します。  

動作確認用として”Terminalスタイル VIA対応ファームウェア”を書き込み済みですので、USB接続するとキーボードとして認識されます。  
下記のMacとWindowsでの確認方法や、スイッチの取り付け箇所の端子部分をピンセットなどでショートして文字を入力するなどの方法で確認してください。

動作確認用のファームウェアを書き込んだ際に全てのキーが正しく反応することを確認済みですが、このタイミングで全てのキーが正しく反応するかを確認しておくと、何かあった場合の問題切り分けがやりやすくなります。

##### Mac, macOS Big Sur 11.2.1

USB接続します。

メニューバーから、``　→　`このMacについて`　→　`システムレポート…` を開きます。

左側の`ハードウェア`で`USB`を選択します。

右側のどこかに`Unison`というデバイスが表示されていれば、接続確認はOKです。

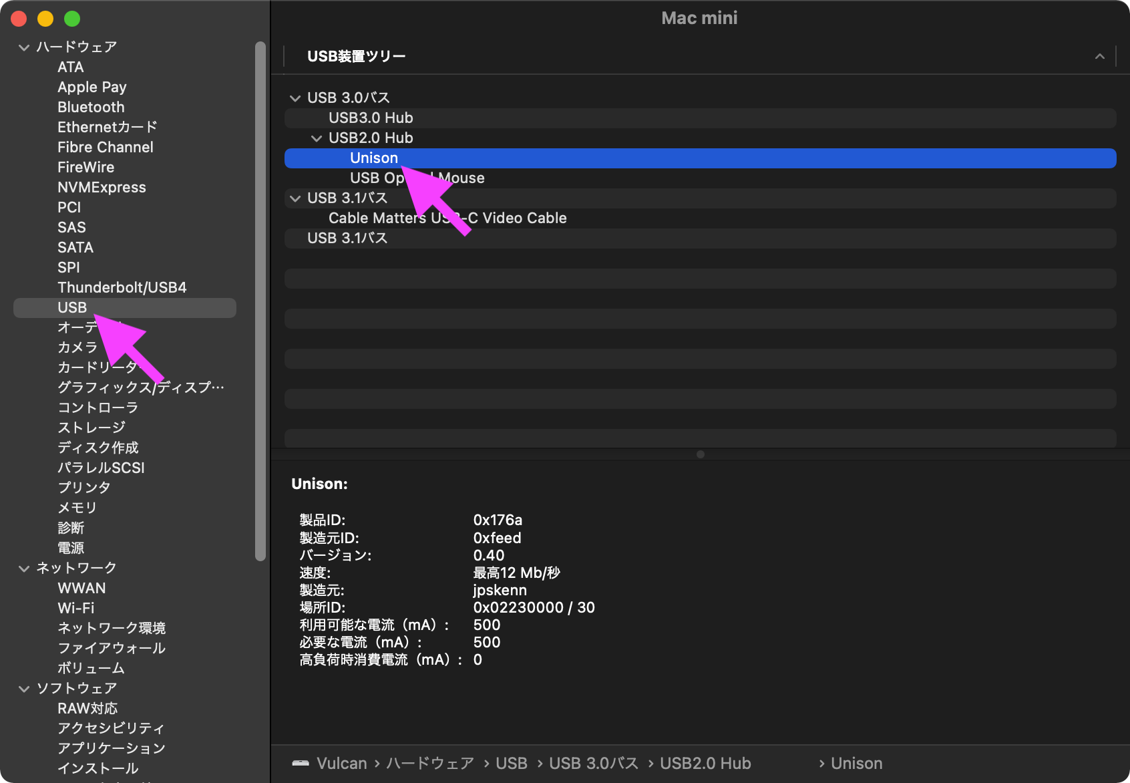
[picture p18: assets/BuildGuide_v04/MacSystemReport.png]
Mac System Report
  
システムレポートの表示

##### Windows, 10 ARM64 Insider Preview - Build 21286

*当方にWindowsをネイティブ動作させる環境がないため、Mac上の仮想環境にインストールした”Windows 10 Client ARM64 Insider Preview - Build 21286”で確認した内容です。*

USB接続します。

`設定` → `Bluetooth とその他のデバイス`を開き、  
`マウス、キーボード、ペン`の項目に`Unison`が表示されていれば、接続確認はOKです。

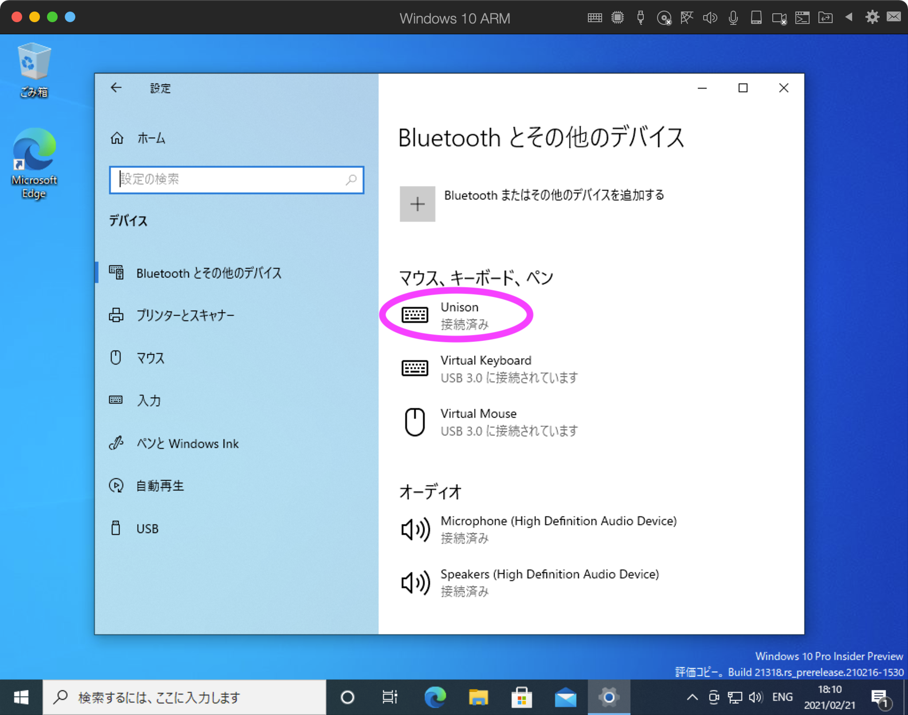
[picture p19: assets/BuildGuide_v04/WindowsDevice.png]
Windows Device Name
  
デバイスの表示

### ファームウェアの書き込み

QMK Toolbox、またはQMKのコマンドなどで書き込んでください。  

なお、動作確認用として”Terminalスタイル VIA対応ファームウェア”を書き込んでいますので、Terminalスタイルを組み立てる場合は、この手順での書き込みは不要です。  

#### QMK Toolbox

[QMK Toolbox](https://docs.qmk.fm/#/ja/newbs_getting_started?id=qmk-toolbox)をダンロードし、使用できる状態にしておきます。  

使用するレイアウト・スタイルに合わせ、QMK Toolbox用hexファイルをダウンロードします。  

- Musicスタイルファームウェア  

    [unison_v04_music.hex](https://gist.github.com/jpskenn/32210c4bdc371ec8600858d6645fd631)

- Terminalスタイル VIA対応ファームウェア  

    [unison_v04_via.hex](https://gist.github.com/jpskenn/c5ac2e3940cbc7818c12e1140436567f)  

`Open`ボタンを押して、ファイル選択ダイアログで書き込むhexファイルを指定します。  

USB接続します。

基板裏側のリセットスイッチを押して、

```console
*** Atmel DFU device connected
```

が表示されることを確認します。  

`Flash`ボタンを押します。

以下のような書き込みメッセージが表示されれば完了です。

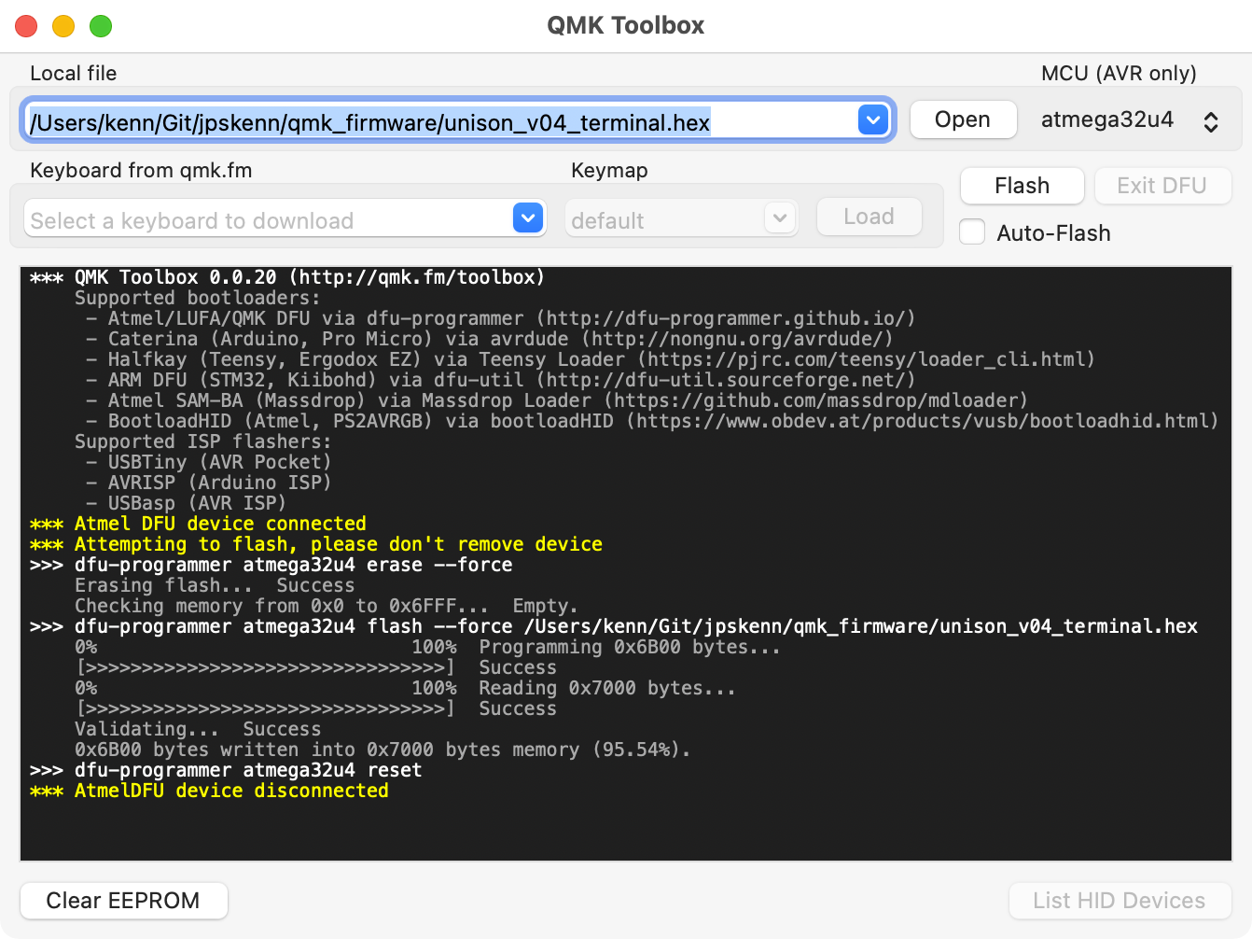
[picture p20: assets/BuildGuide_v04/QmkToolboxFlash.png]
QMK Toolbox message
  
ファームウェアの書き込みメッセージ  
（ファイル名や%の数値などは実際と異なる場合があります）

#### QMKコマンド

”[QMK環境の構築：ビルド環境を準備する](https://docs.qmk.fm/#/ja/newbs_getting_started?id=set-up-your-environment)”を参考に、QMKのビルド環境を構築しておきます。

*現在のところ、Unison関連ファイルは本家QMKには取り込まれていませんので、私がフォークしたリポジトリから取得してください。*

[jpskenn/qmk_firmware: develop_Unisonブランチ](https://github.com/jpskenn/qmk_firmware/tree/develop_Unison/)をダウンロードします。

ダウンロードした中の`keyboards`ディレクトリ配下の`unison`ディクトリを、先ほど構築したQMKの`keyboards`ディレクトリ配下へ配置します。  

キーレイアウトに合わせて、いずれかのコマンドを実行します。

- Musicスタイル  

    ```console
    qmk flash -kb unison/v04 -km music
    ```

- Terminalスタイル（テンキー中央）

    ```console
    qmk flash -kb unison/v04 -km via
    ```

何やら画面に表示された後、しばらくすると次のようなメッセージが繰り返し表示されます。

```console
dfu-programmer: no device present.
ERROR: Bootloader not found. Trying again in 5s.
```

キーボードのリセットスイッチを押すと書き込みが始まります。

次のようなメッセージが表示されたら完了です。  
（%の数値などは実際とは異なる場合があります）

```console
Bootloader Version: 0x00 (0)
Erasing flash...  Success
Checking memory from 0x0 to 0x6FFF...  Empty.
0%                            100%  Programming 0x6900 bytes...
[>>>>>>>>>>>>>>>>>>>>>>>>>>>>>>>>]  Success
0%                            100%  Reading 0x7000 bytes...
[>>>>>>>>>>>>>>>>>>>>>>>>>>>>>>>>]  Success
Validating...  Success
0x6900 bytes written into 0x7000 bytes memory (93.75%).
```

### （オプション）LEDの取り付け

基板裏側でジャンパし、おもて側へLEDを取り付けます。

#### LEDの取り付け箇所

LEDの取り付け箇所は、次の3グループに分かれています。

- インジケータ 2個：`L1`,  `L2`
- ロータリーエンコーダの隣（以降、REサイドと呼称） 5個：`L3 R.E.`, `L6 R.E.`, `L7 R.E.`, `L8 R.E.`, `L9 R.E.`
- 追加オプション 2個：`L4 Opt.`, `L5 Opt.`

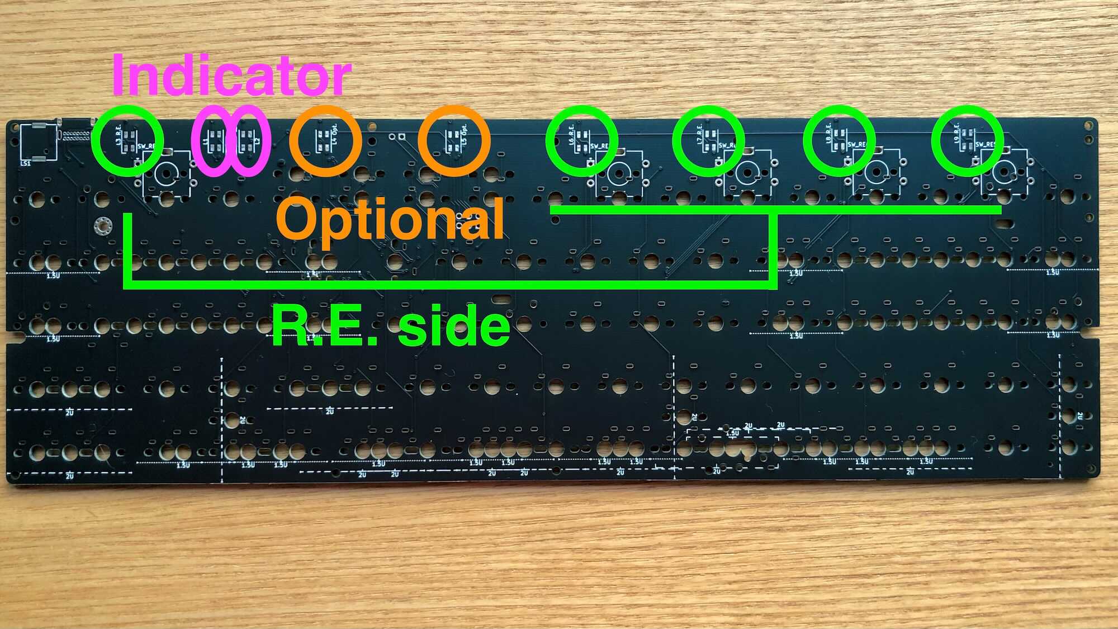
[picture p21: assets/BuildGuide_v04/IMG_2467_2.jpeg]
LED Group


#### LEDグループの組み合わせ

LEDグループの組み合わせは、以下の表のとおりです。

| 組み合わせ | インジケータ | REサイド | 追加オプション |
| :--: | :--: | :--: | :--: |
| A | あり | なし | なし |
| B | あり | あり | なし |
| C | あり | あり | あり |

表に載っていない「REサイド：なし、追加オプション：あり」などは、無効な組み合わせです。

#### ファームウェアに定義されたLEDの設定

ファームウェアに定義されているLEDの設定は、次のとおりです。  
これ以外の組み合わせや、LEDの数が異なる場合は、ファームウェアの定義を変更してください。

- Musicスタイル  
    組み合わせB：インジケータ（2個） ＋ REサイド（5個） ＋ LEDテープ（8個）

- Terminalスタイル  
    組み合わせC：インジケータ（2個） ＋ REサイド（5個） ＋ 追加オプション（2個） ＋ LEDテープ（8個）

なお、インジケータLEDの2個だけを取り付けて、点灯させることができます。  
この場合はファームウェアの変更は不要です。

#### 取り付けるLEDに応じたジャンパ

LEDをどの組み合わせで取り付けるか確認します。

REサイドのLEDを使用する場合は、基板裏側のジャンパ`R.E. LEDs`を`Enable`に、使用しない場合は`Disable`にジャンパします。

追加オプションのLEDを使用する場合は、基板裏側のジャンパ`Opt. LEDs`を`Enable`に、使用しない場合は`Disable`にジャンパします。

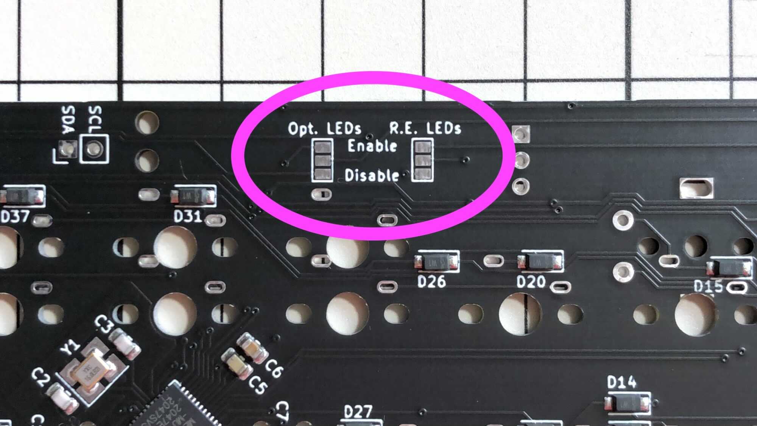
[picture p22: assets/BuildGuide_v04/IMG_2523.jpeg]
LEDジャンパ位置
  
LEDジャンパ位置

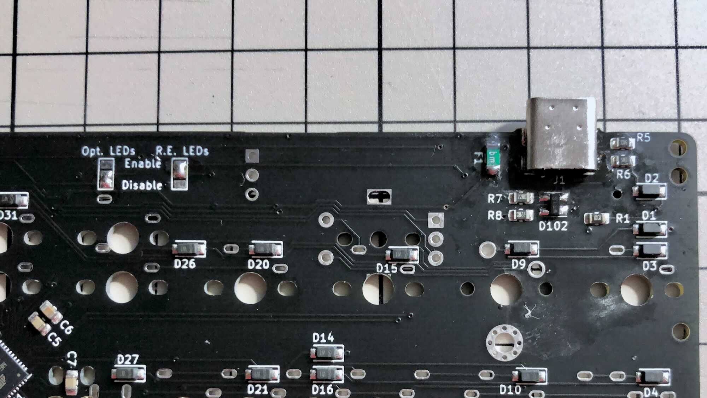
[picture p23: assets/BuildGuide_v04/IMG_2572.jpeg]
LEDジャンパ例
  
`R.E. LEDs`を`Enable`に、`Opt. LEDs`を`Disable`にジャンパした例

#### LEDの取り付け

基板おもて側から、選んだ組み合わせのLED取り付け位置を確認します。  

LEDの取り付け方向は、発光面の切り欠きマーク（▲）が、設置位置を示す短い横線に合う方向です。

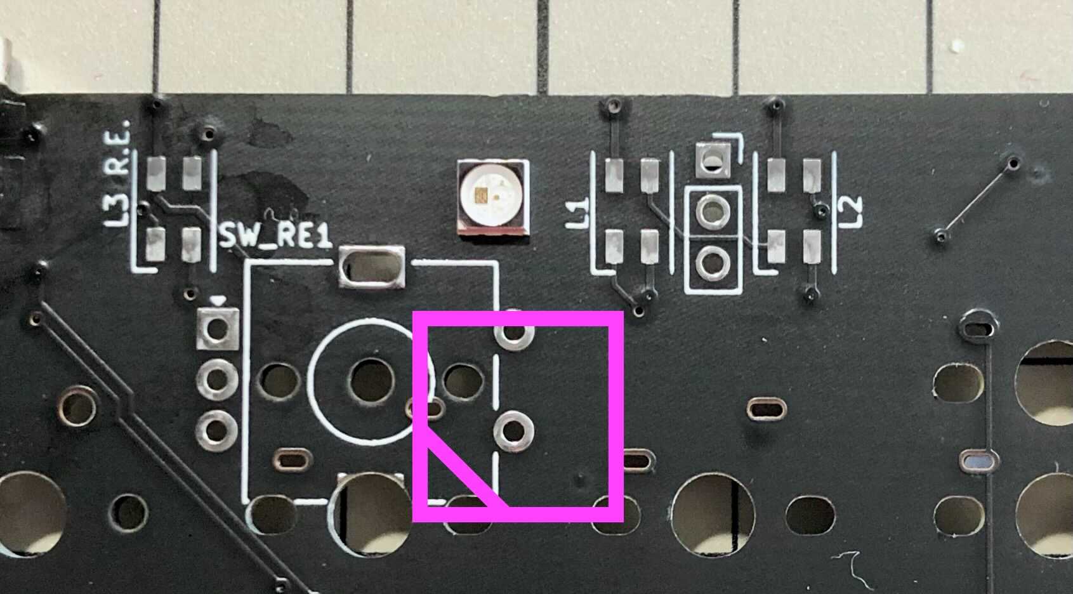
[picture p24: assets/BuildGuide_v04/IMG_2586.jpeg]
LED取り付け方向

LED取り付け方向

LEDは高温ではんだ付けすると壊れるため、コテ先温度を220-270℃に設定します。  
使用するはんだの種類や作業手順にもよりますが、220℃では加熱不足によるはんだ不良に注意してください。  
[加熱不足による、はんだ不良の例](https://twitter.com/jpskenn/status/1291328876283478016)

また、フラックスを塗っておくとはんだ付けしやすくなります。

取り付け位置のLEDのパッドのうち、1箇所だけに予備はんだしておきます。

LEDを基板に置きます。

予備はんだした箇所をはんだ付けします。  
ピンセットでLEDをつまみ、位置がずれないようにします。  
LEDの横方向からパッドとLEDにコテ先をあて、1、2と数えてコテ先を離します。  
さらに1、2と数えてLEDを固定していたピンセットを離します。  
はんだが小さな球のようになっていれば良い仕上がりです。

LEDの位置がずれていないことを確認します。

残りのパッド3箇所をはんだ付けします。  
予備はんだ以外の3箇所は、少量のはんだをコテ先に乗せておき、先ほどと同様の手順をおこないます。

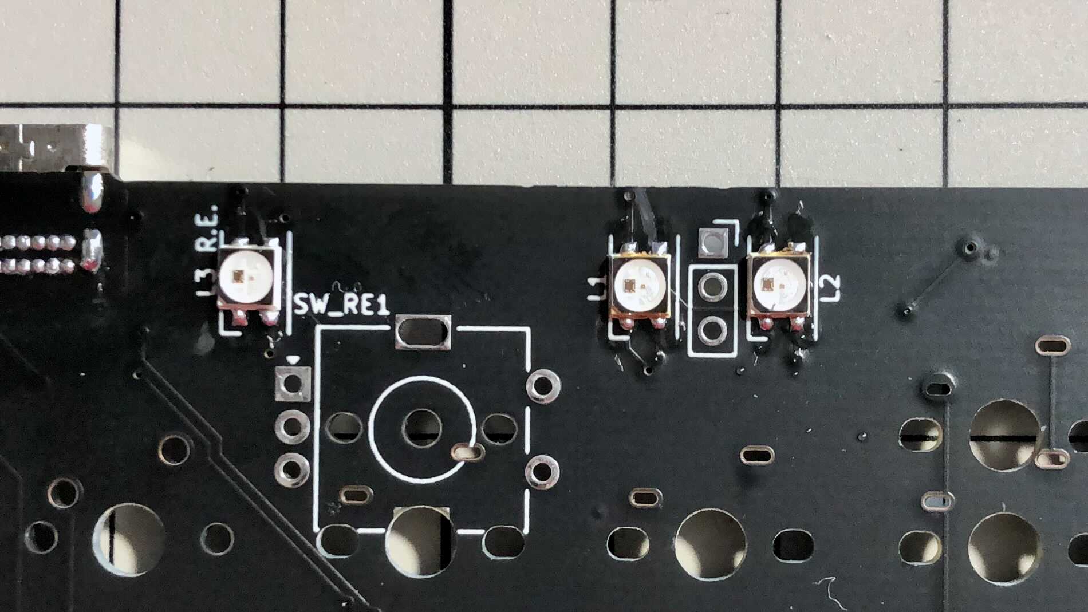
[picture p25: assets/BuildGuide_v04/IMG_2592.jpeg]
取り付けたLED

取り付けたLED

### （オプション）スピーカーの取り付け

基板おもて側にスピーカーを取り付けます。

取り付け場所が狭く、スペーサーと干渉しやすいため、四角の枠内でUSBコネクタ側に寄せるようにして取り付けます。  
スペーサーを仮に取り付けた状態で取り付けると、わかりやすくなります。

基板おもて側、スピーカー`LS1`のパッド2箇所のうち、片方だけに予備はんだしておきます。

スピーカーの端子部をパッドに合わせて置きます。  
どちらの方向に取り付けても大丈夫です。  

予備はんだした箇所をはんだ付けします

スピーカーがまっすぐ取り付けられていることを確認します。

残りの1箇所をはんだ付けします。

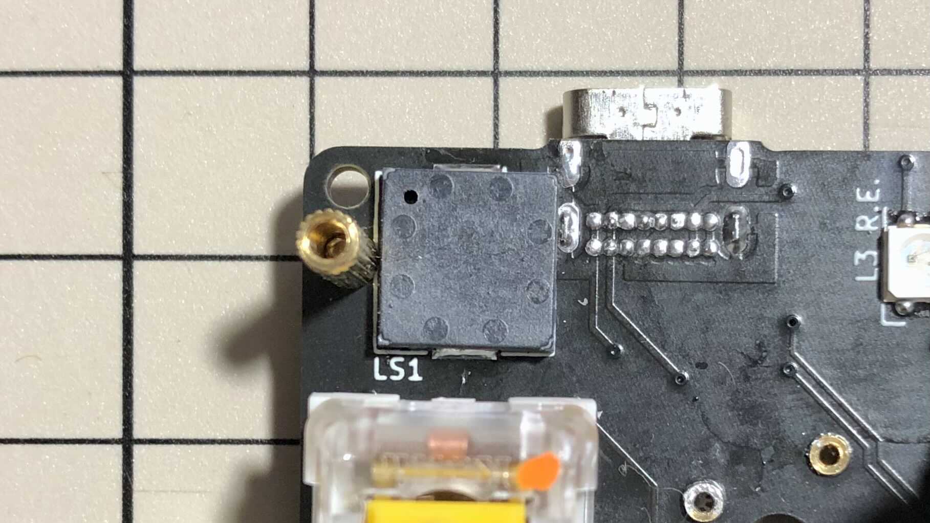
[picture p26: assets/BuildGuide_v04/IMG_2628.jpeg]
取り付けたスピーカー

取り付けたスピーカー

### スイッチソケットの取り付け

基板裏側から取り付けます。

`左上`, `左下`, `右上`, `右下`, `中央`の5箇所のネジ穴にかぶさるスイッチは、ソケットを介して取り付けます。  
v04ではMill-Maxソケットを取り付けます。  
なお、`左下`と`右下`で1.5uのキーを使用する場合や、`中央`をネジ止めせずに使用する場合は、該当箇所へのソケット取り付けは不要です。

スイッチを1個用意し、スイッチの端子にMill-Maxソケットを差し込みます。  
差し込む際に端子を曲げてしまいやすいので注意してください。

*細かい部品のはんだ付けに不安がある場合は、失敗した場合にそなえ、どうなっても良いスイッチを使用することをおすすめします。*  
*スイッチの端子とソケットがはんだでくっついてしまったり、加熱しすぎてスイッチが溶けたりすることがあります。*

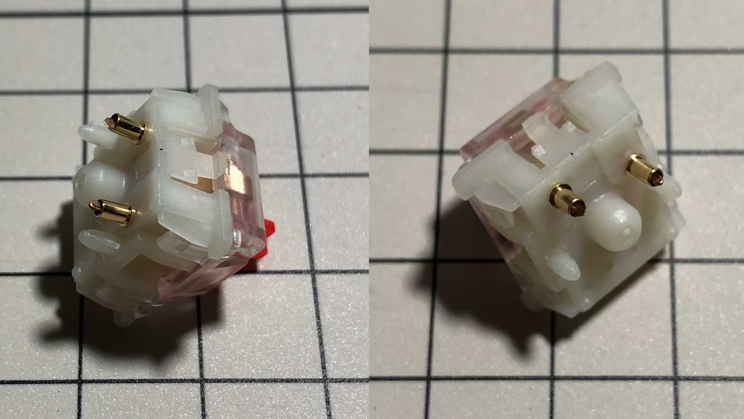
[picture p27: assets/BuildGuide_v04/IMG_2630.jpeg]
Mill-Maxソケットを差し込んだスイッチ

Mill-Maxソケットを差し込んだスイッチ

Mill-Maxソケットを差し込んだスイッチを、基板へはめ込みます。  
固定がゆるい場合は、マスキングテープなどを貼って仮止めしておきます。

基板を裏返し、Mill-Maxソケットをはんだ付けします。  
はんだをつけすぎて、ソケット先端からスイッチの端子へ流れ込まないように注意してください。  
こて先をソケット先端から少し離しておくと、流れ込みにくくなります。

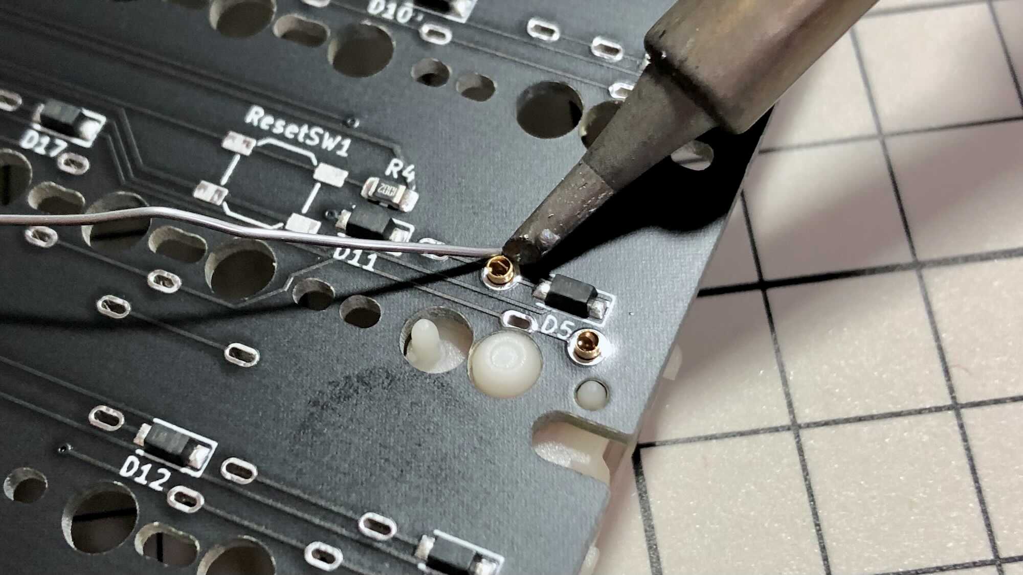
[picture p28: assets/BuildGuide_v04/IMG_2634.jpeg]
ソケット取り付けの様子

ソケット取り付けの様子

スイッチを取り外します。

基板おもて側から見て、ソケットが奥まで差し込まれてはんだ付けされていることを確認します。  
ソケットのツバと基板に隙間があいて少し浮いているような場合は、基板おもて側からソケットをはんだごてで加熱しながら慎重に押し込みます。

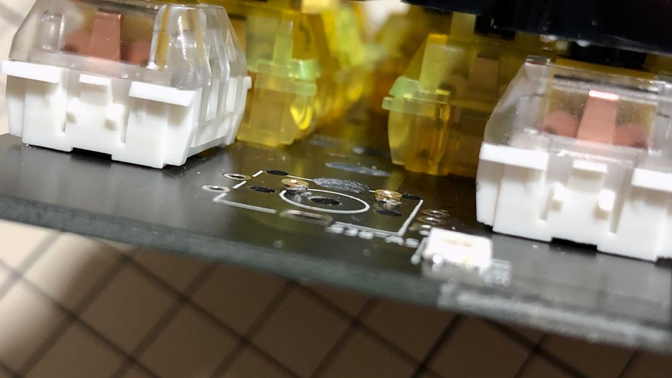
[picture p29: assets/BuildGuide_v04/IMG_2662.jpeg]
取り付けたソケット, 基板おもて側

取り付けたソケット, 基板おもて側

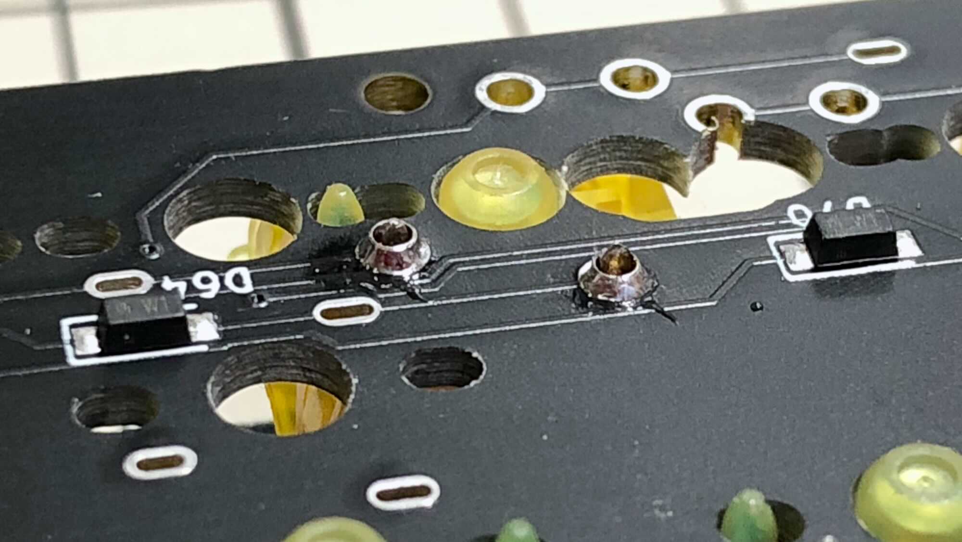
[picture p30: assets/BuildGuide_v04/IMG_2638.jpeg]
取り付けたソケット, 基板裏側

取り付けたソケット, 基板裏側

### キースイッチの取り付け

基板おもて側からスイッチを取り付けます。

取り付けを始める前に、スイッチの端子が真っ直ぐになっていることを確認しておきます。

使用するレイアウト・スタイルに対応する位置へ、スイッチを基板にはめ込みます。  
[KeyboardLayoutEditor: Musicスタイル](http://www.keyboard-layout-editor.com/#/gists/866c93c6eb4c580be0cf582207fa1836)  
[KeyboardLayoutEditor: Terminalスタイル](http://www.keyboard-layout-editor.com/#/gists/f8cf33730eca47e1e9039568cd3ca72c)

*なお、中央下側のネジ穴にかぶさるスイッチは、後述の[スイッチ足の加工](#スイッチ足の加工)をおこなってからはめ込みます。*

はめ込んだスイッチの固定がゆるい場合は、マスキングテープなどを貼って仮止めしておきます。
5個や10個ずつ作業を進めると確実です。

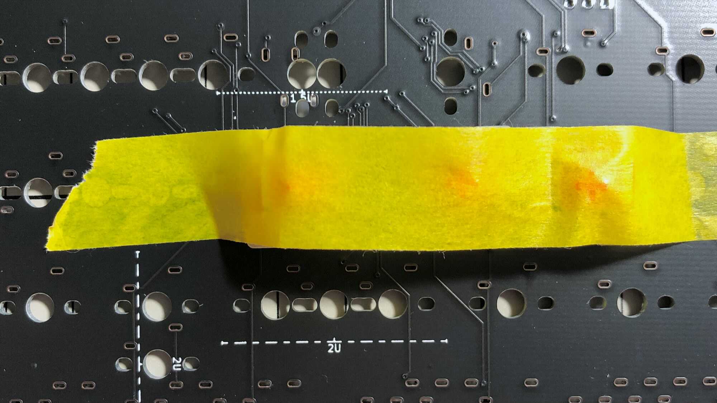
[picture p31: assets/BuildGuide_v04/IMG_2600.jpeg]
はめ込んだスイッチを仮止めした様子

はめ込んだスイッチを仮止めした様子

スイッチが外れないように注意しながら、基板を裏返します。

各スイッチの端子の**片方だけ**をはんだ付けします。

基板をおもて側にして、スイッチが傾かず、奥までしっかりとはまって取り付けられていることを確認します。  
傾きがある場合などは、スイッチの端子をはんだごてで加熱して調整します。

基板をもう一度裏返して、残った端子をはんだ付けして固定します。

作業を繰り返し、残りのスイッチを取り付けます。

#### スイッチ足の加工

中央下側のネジ穴にかぶさるスイッチを取り付けるには、スイッチ足の加工が必要です。

スイッチの取り付け位置、スイッチの形状、使用するケースなどによって加工内容が変わるので、現物合わせで加工します。

- 5pinスイッチの足が干渉する場合

    干渉する方の足をニッパーなどで切り取ります。

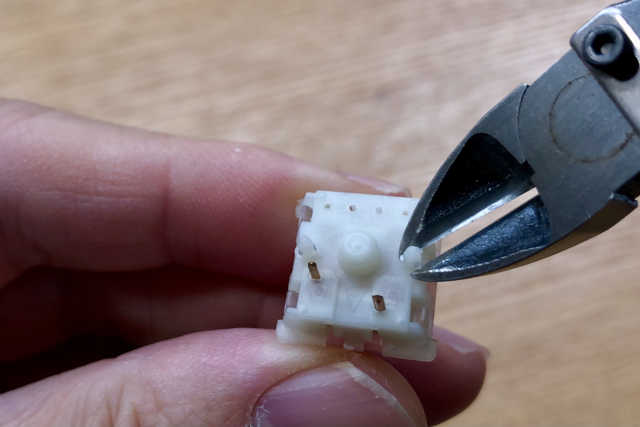
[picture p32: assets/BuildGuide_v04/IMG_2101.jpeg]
片方の足を切り取る様子
      
    片方の足を切り取る様子

- 中央の足（でっぱり部分）が干渉する場合

    中央の足（でっぱり部分）を、ケースのネジ穴に当たらない程度にカットします。  
    場合によっては全てカットすることもあります。

    押下時に軸がネジに当たる場合は、軸の下端もカットします。  

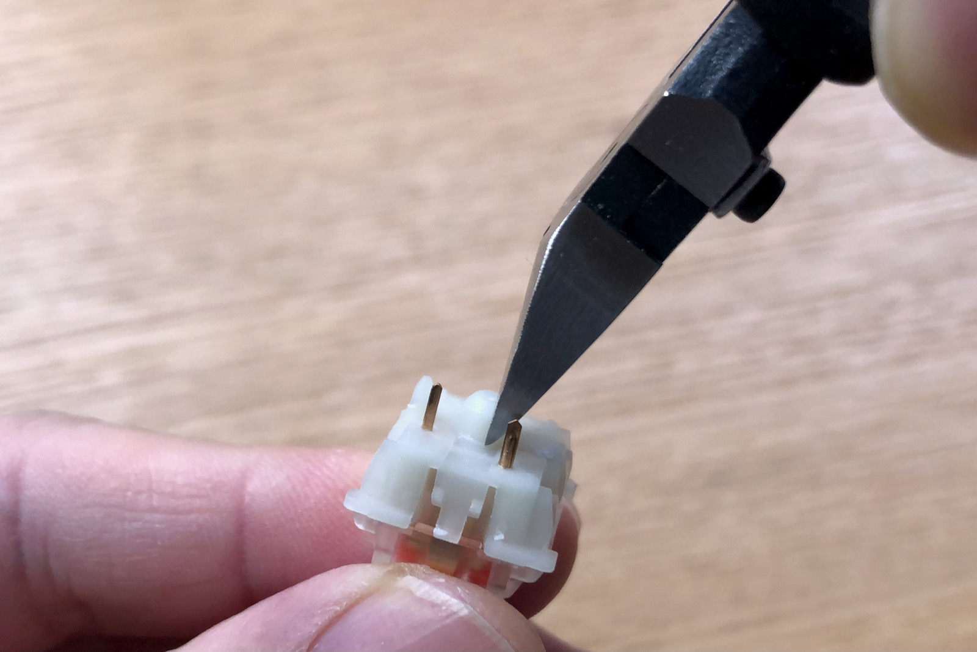
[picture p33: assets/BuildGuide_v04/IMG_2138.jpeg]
縦に切れ込みを入れる様子
      
    縦に切れ込みを入れる様子

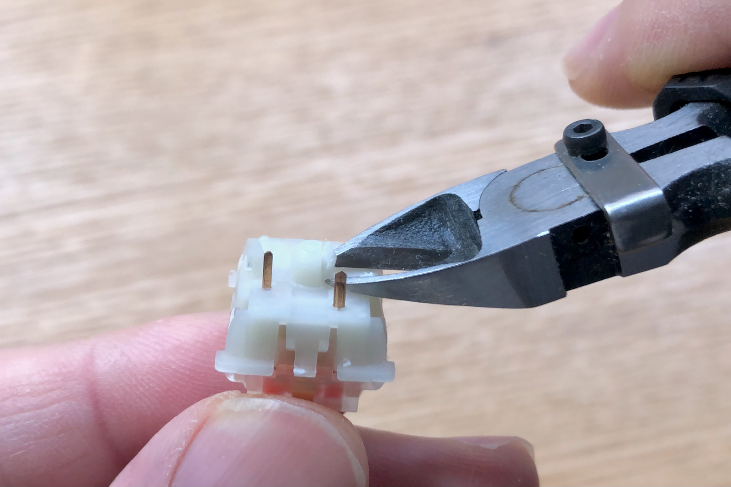
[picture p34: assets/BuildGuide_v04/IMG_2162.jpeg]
切れ込みを入れたところまでカットする様子
      
    切れ込みを入れたところまでカットする様子

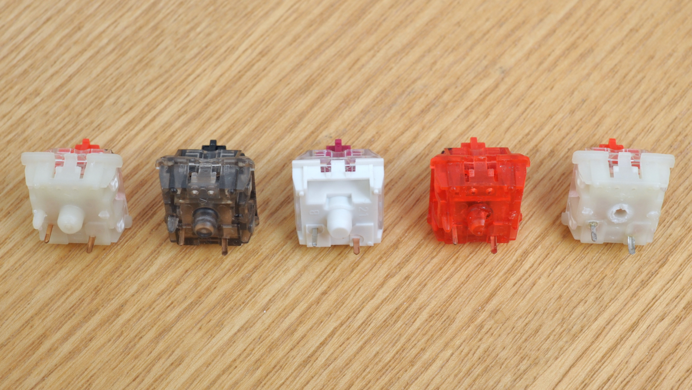
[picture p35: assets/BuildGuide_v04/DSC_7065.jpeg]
足をカットしたスイッチ
      
    足をカットしたスイッチ  
    左から順に  
  - Gateron Silent Red 5pin：片方の足をカット
  - Gateron Ink Black 5pin：片方の足をカット
  - Kailh Pro Burgundy 3pin：無加工
  - Gateron Ink Red 5pin：片方の足をカット、中央の足を1/3カット
  - Gateron Silent Red 5pin：両方の足をカット、中央の足を全てカット

### （オプション）ロータリーエンコーダの取り付け

基板おもて側から取り付けます。

取り付け位置は、`SW_RE1`から`SW_RE5`の5箇所です。

ピンと足の位置を合わせて基板に差し込みます。  
足が差し込みにくいときは、横から少し押さえて差し込みます。

基板裏側から、何本かあるピンのうち1本だけをはんだ付けします。

ロータリーエンコーダがまっすぐ取り付けられていることを確認します。

残りのピンをはんだ付けします。

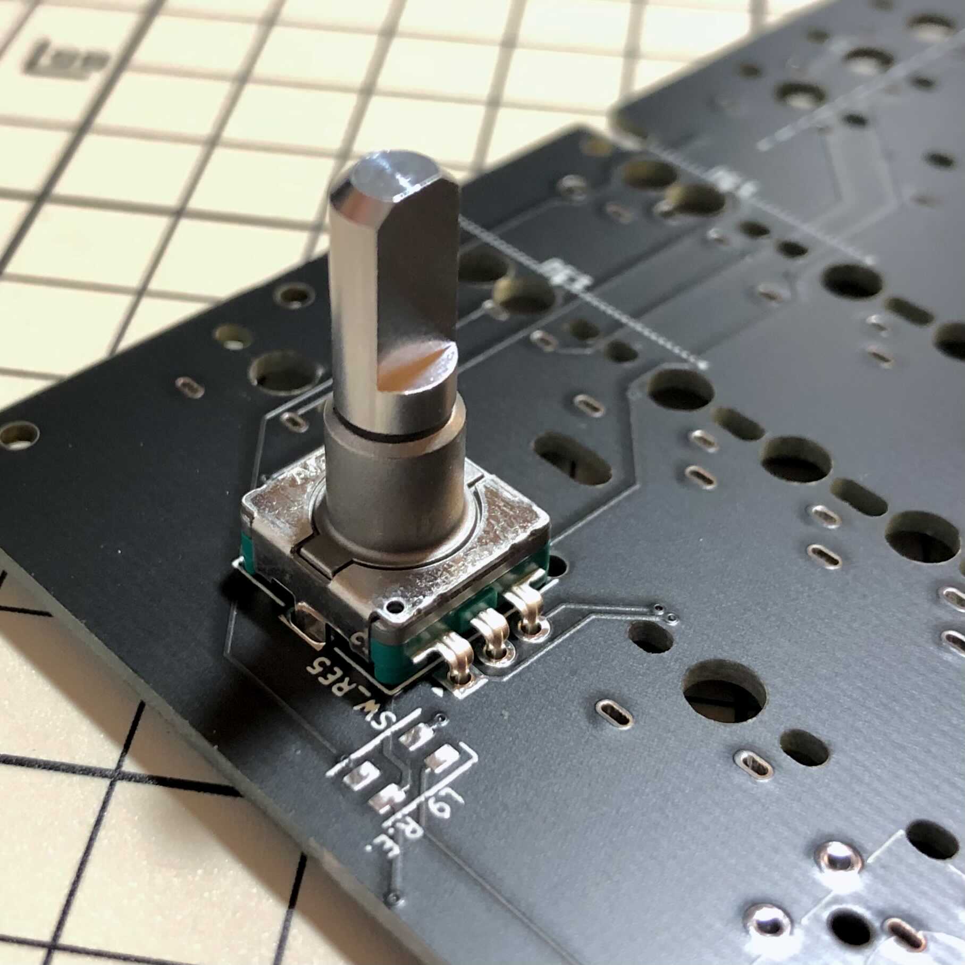
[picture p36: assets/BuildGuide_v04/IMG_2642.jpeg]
取り付けたロータリーエンコーダ（基板おもて側）

取り付けたロータリーエンコーダ（基板おもて側）

### （オプション）LEDテープの取り付け

基板裏側から`LED Strip`へ取り付けます。

LEDテープの取り付け位置を確認し、使用する長さにカットしておきます。  
基板上の部品などとのショートが心配される箇所は、絶縁のためにカプトンテープなどを貼っておきます。

基板のLEDテープ用パッドの、`+5V`, `LED`, `GND`の3箇所に予備はんだしておきます。

LEDテープをパッドに重ね、端子部分をコテ先で押さえつけるようにして、真ん中の`LED`パッドだけをはんだ付けします。

LEDテープがまっすぐ取り付けられていることを確認します。

残りの`+5V`と`GND`のパッドをはんだ付けします。

テープを貼り付けます。  
LEDテープ自体のシール部分を使わず、カプトンテープなどで貼り付けておくと、後からメンテナンスしやすいかもしれません。

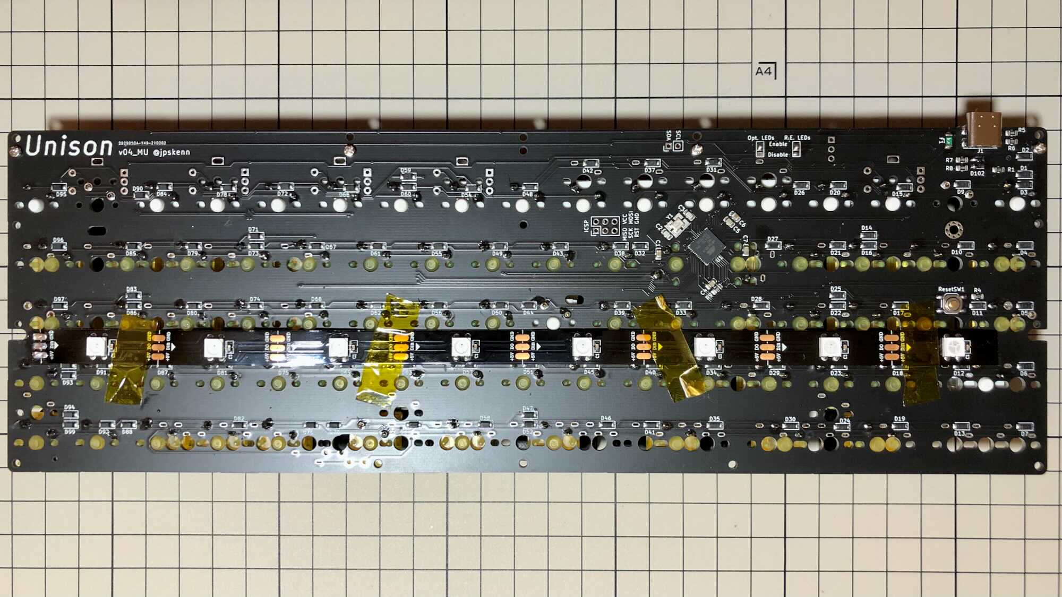
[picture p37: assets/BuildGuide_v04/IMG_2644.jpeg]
LEDテープを取り付けた状態, カプトンテープで貼り付け
  
LEDテープを取り付けた状態, カプトンテープで貼り付け

### 動作確認

ケースへ取り付ける前に、キーボードをPCやMacに接続して動作確認を行います。

#### キースイッチの動作確認

確認の前に、OSの設定方法に従い、OSが認識するキーボードの配列を英語キーボード（ANSI）に合わせておきます。

キースイッチの動作確認は、OSのキーボードビューアや、[Keyboard Checker](https://keyboardchecker.com)、[QMK Configrator](https://config.qmk.fm/)の入力テスト機能を使用して行います。  
全てのキーで正常に入力できることを確認します。

なお、初めてキーボードを使用する際はMac向けのキーマップに設定されているため、Windows環境では`ALT`と`Win`が逆に認識されます。  
使用するファームウェアに合わせて、キーの配置を切り替えてください。

- Musicスタイル  

    Windows向けのキーマップへは`Lower + Raise + W`を、Mac向けのキーマップへは`Lower + Raise + Q`のキーを同時に押すと切り替わります。 （ベースレイヤーの切り替え）  
    切り替えれた状態は記憶されます。  
    ※`Lower`は左スペース、`Raise`は右スペースの長押し。

- Terminalスタイル  

    後述の[RemapまたはVIAによるキーマップの変更](#RemapまたはVIAによるキーマップの変更)を参考に、各ツールを使用してキーの配置を切り替えます。

正常に入力できないキーがあった場合は、原因を調査し、修復します。

特定のスイッチ1個だけが入力できない場合、もっとも多い原因は、スイッチの取り付け不良です。  
はんだ不良や、片方の端子をはんだ付けし忘れていたりしていないか確認します。  

上記で解決できなかった場合、基板のスイッチ取り付け部分の端子をピンセットなどを使ってショートさせ、キー入力されるか確認します。  
キー入力された場合は、スイッチに問題があるため、再度取り付けの不良を確認します。  
それでも改善されない場合は、スイッチを別のものに交換します。

スイッチ1個だけではなく、1行や1列のスイッチが入力できない場合は、基板の損傷や実装された部品へのダメージなどが原因と考えられます。  
これまでの軽微な作業ミスが原因だった場合とは異なり、原因箇所の特定にはテスターを使った詳しい調査が必要となり、修復の難易度も高くなることが予想されます。  
[Unison v04_MU KiCadプロジェクト](https://github.com/jpskenn/Unison/releases/tag/v04_MU)のPCB設計を参照し、パッド、ダイオード、MCUのピンなどの導通を確認して調査します。  
なお、自分ひとりでは解決できない場合、[Twitter: @jpskenn](https://twitter.com/jpskenn/)へご一報いただければ、何か情報共有できるかもしれません。

#### ロータリーエンコーダの動作確認（Musicスタイルのみ）

`Lower`と`Raise`を同時に押しながらロータリーエンコーダのつまみを回し、OSの音声出力ボリュームが変化することを確認します。  

プッシュボタンスイッチ付きのロータリーエンコーダでは、`Lower`と`Raise`を同時に押しながらプッシュすると、OSの音声出力がミュート／ミュート解除されることを確認します。

動作不良の場合は、はんだ付けをやり直してください。

#### LEDの動作確認

取り付けたLEDがすべて点灯していれば正常です。

インジケータの2個以外が消灯している場合、`Lower + Raise + L`でLEDの点灯オン／オフを切り替えて確認します。

光らない箇所がある場合は、次の原因が考えられるため、それぞれに応じた対応をおこないます。

- [取り付けるLEDに応じたジャンパ](#取り付けるLEDに応じたジャンパ)がおこなわれていない  

    → 正しくジャンパする。

- [ファームウェアに定義されたLEDの設定](#ファームウェアに定義されたLEDの設定)と取り付けたLEDの個数、場所が異なっている

    → ファームウェアの定義を変更し、ファームウェアを書き換える。

- 光らないLEDの取り付けに問題がある

    → 光らないLEDのはんだ付けをやり直す

- 光らないLEDのひとつ前のLEDの取り付けに問題がある（ひとつ前のLEDから信号が届かないため光らない）

    → ひとつ前のLEDのはんだ付けをやり直す

なお、LEDグループの組み合わせによるLEDの並び順は、次のとおりです。

- 組み合わせA：インジケータ

    `L1`,  `L2`, `LEDテープ`

- 組み合わせB：インジケータ  ＋ REサイド

    `L1`,  `L2`, `L3 R.E.`, `L6 R.E.`, `L7 R.E.`, `L8 R.E.`, `L9 R.E.`, `LEDテープ`

- 組み合わせC：インジケータ ＋ REサイド ＋ 追加オプション

    `L1`,  `L2`, `L3 R.E.`, `L4 Opt.`, `L5 Opt.`, `L6 R.E.`, `L7 R.E.`, `L8 R.E.`, `L9 R.E.`, `LEDテープ`

220-270℃で1、2と数える程の加熱ではそう簡単にはLEDは壊れないと考えますが、何度かはんだをやり直しても点灯しない場合は、LEDが壊れていると判断して新しいものに交換します。

（参考）主なLED関連キーは次の通りです。

```plaintext
Lower + Raise + L  LED点灯のオン／オフ
Lower + Raise + Lの右隣のキー（;）　次の点灯モードに切り替え
Lower + Raise + P　前の点灯モードに切り替え
Lower + Raise + I　LEDの輝度増加
Lower + Raise + K　LEDの輝度低下
```

#### スピーカーの動作確認（Terminalスタイルのみ）

キーボードを接続した際、♪ピロッという音が鳴っていれば確認OKです。

音が鳴らない場合は、`Lower + Raise + A`でスピーカーのオン／オフを切り替えて確認します。

音が鳴らない場合は、スピーカーのはんだ付けをやり直します。

主なスピーカー関連キーは次の通りです。

```plaintext
Lower + Raise + A　スピーカーのオン／オフ切り替え
Lower + Raise + S　タイプ音のオン／オフ切り替え
Lower + Raise + A　ミュージックモードのオン／オフ切り替え
```

### プレート用スペーサーの取り付け

基板おもて側にスペーサーを取り付け、裏側からねじ止めします。

スペーサーの取り付け位置は次のとおりです。

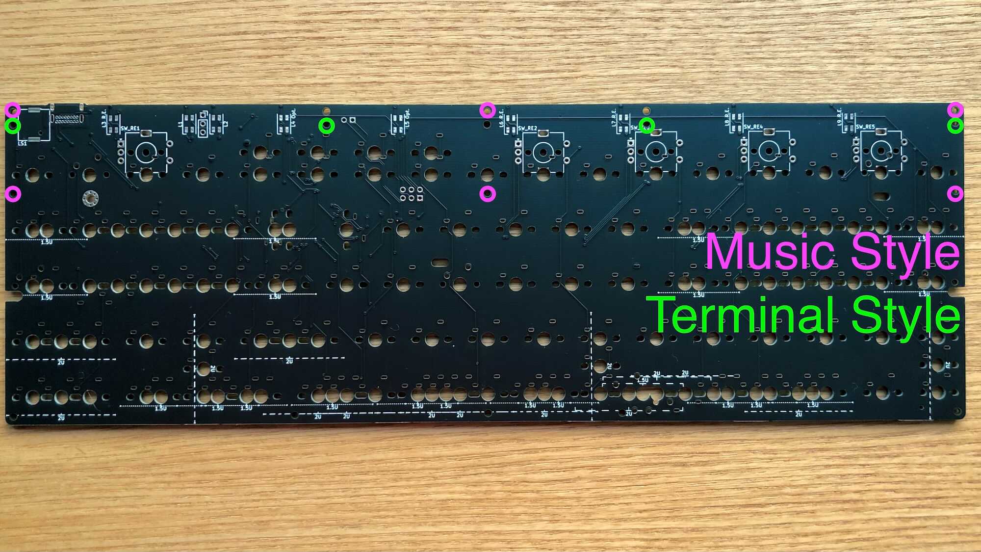
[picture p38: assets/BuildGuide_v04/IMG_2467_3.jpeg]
スタイル・レイアウトごとの取り付け位置

スタイル・レイアウトごとの取り付け位置

取り付け位置にスペーサーを配置し、基板裏側からM2 5mmのネジで止めます。  
ギュウギュウとネジを締め込むと基板が破損する場合がるため、スペーサーが軽く止まってネジが緩んでこない程度にしておきます。

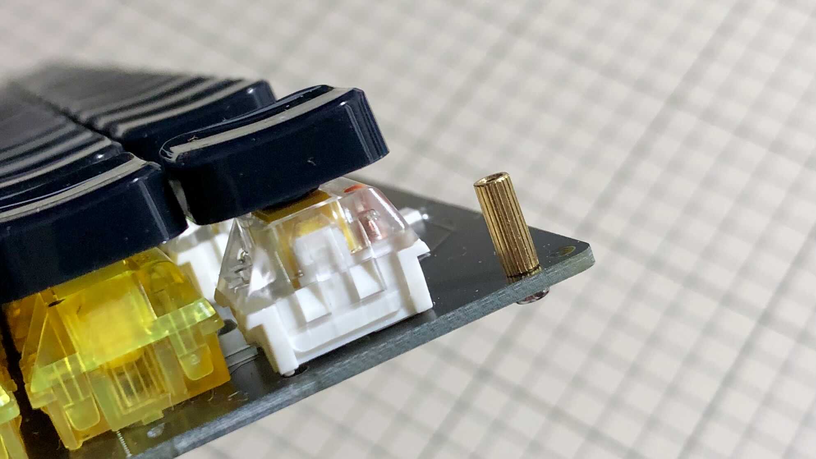
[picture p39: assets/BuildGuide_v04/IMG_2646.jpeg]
スペーサーを取り付けた状態, Terminalスタイル

スペーサーを取り付けた状態, Terminalスタイル

メモ：  
組み合わせるケースによっては、プレートが高すぎたり低すぎることがあります。  
ちょうど良い長さのスペーサーに交換して、一番格好良いと思える高さを探してください。  

### （該当者のみ）60% プラスチックケースの加工

60% プラスチックケースへ取り付ける際は、ネジ穴と同じ高さのケース内リブが基板上の部品と干渉するため、以下の加工を行います。

カットする箇所を確認します。  
以下に示す、ケースネジ穴と同じ高さになっているリブがカットする箇所です。  

- 左の上側ネジの上と下。
- 右の上側ネジの上と下。
- 中央付近、左右に長いリブ2本。
- ケース一番下の長いリブのうち、スイッチの端子などに当たる部分。  

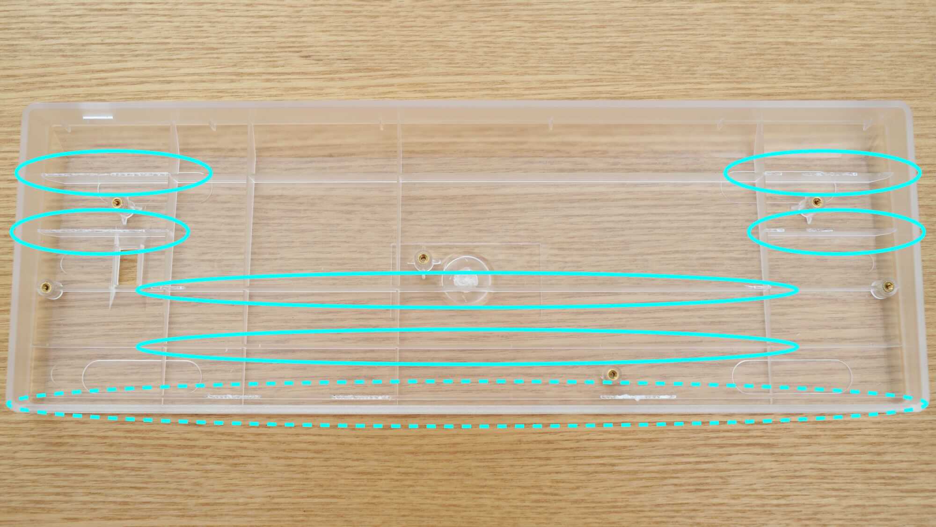
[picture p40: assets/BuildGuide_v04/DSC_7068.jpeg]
カット箇所

カット箇所

写真で示した部分を、ニッパーやカッターなどを使ってカットします。  
ニッパー使用時は、1-2mmくらいずつ切り進んでいきます。  
それ以上の長さをカットすると、意図しないところまで割れてしまうことがあります。

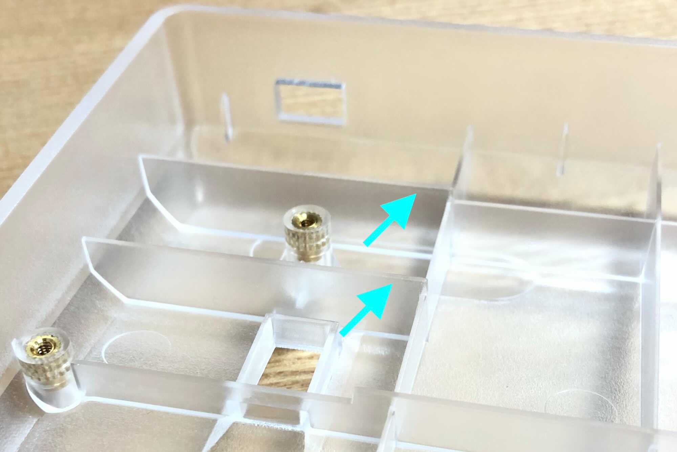
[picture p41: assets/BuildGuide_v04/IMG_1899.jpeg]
カット前：左の上側ネジの上と下

カット前：左の上側ネジの上と下

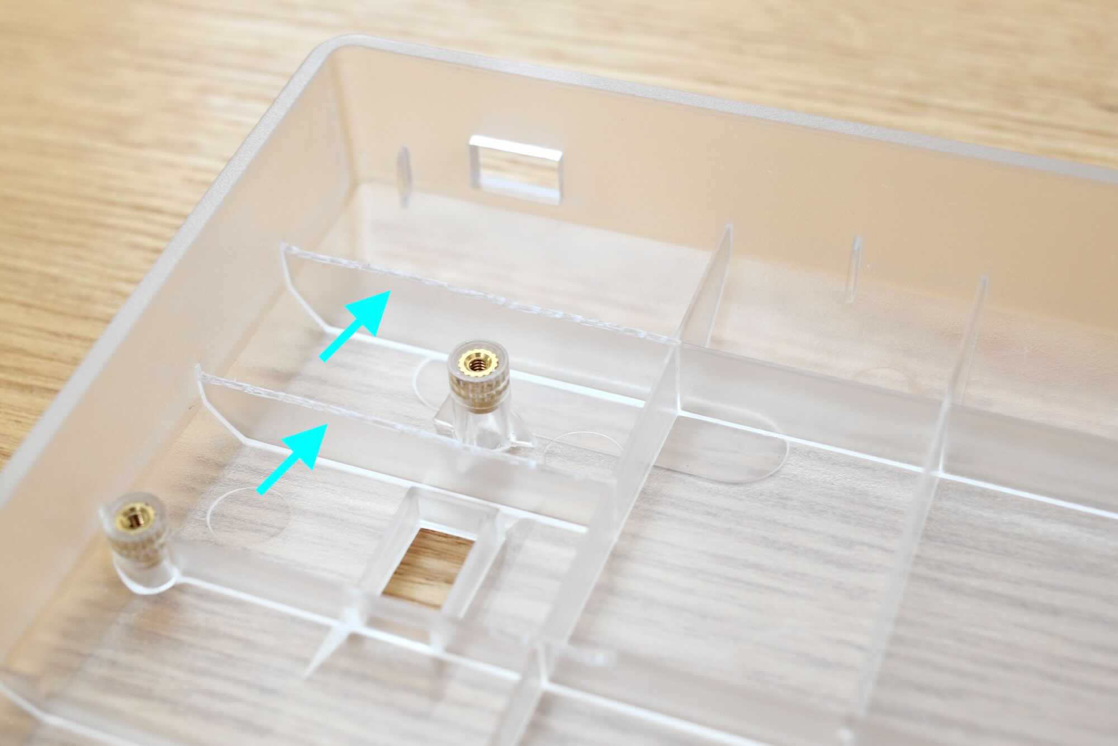
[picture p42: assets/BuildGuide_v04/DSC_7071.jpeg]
カット後：左の上側ネジの上と下

カット後：左の上側ネジの上と下

### ケースへの取り付け

取り付け前に、ネジ穴にかぶさるスイッチは外しておきます。

基板の奥側（USBコネクタ側）からケース内へ入れていきます。  
ケースに対して基板を30度くらいの角度で差し込むと、USBコネクタがケースの穴にスッとはまります。  
その状態で基板の手前側をおろして水平にすると、力をかけることなく、基板全体がストンとケースに入ります。  
力を入れてグリグリとこじったり、ググググッと押し込むようなことはせず、角度を合わせて差し込むだけです。

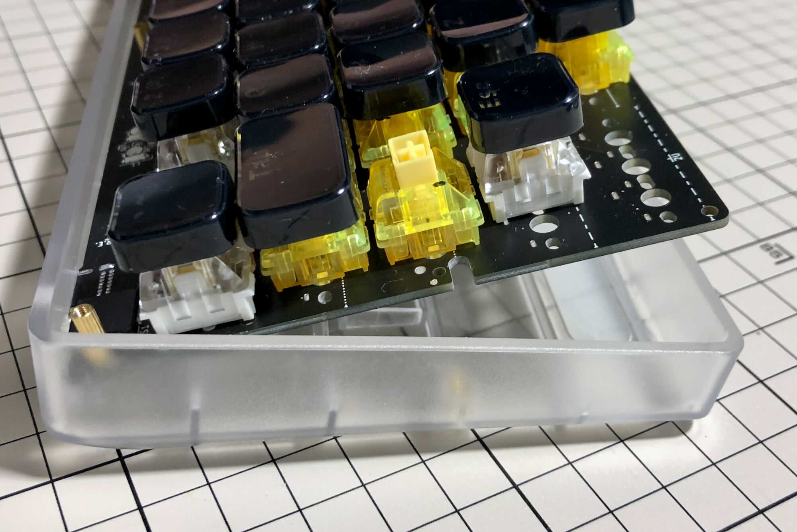
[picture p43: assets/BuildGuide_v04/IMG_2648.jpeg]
30度で差し込む様子

30度で差し込む様子

ケースネジ穴と基板のネジ穴の位置を合わせ、`左上`, `左下`, `右上`, `右下`, `中央`の5箇所を、M2 5mmの低頭ネジで仮止めします。  
なお、`中央`をネジ止めせずに使用する場合は、`中央`を除いた4箇所となります。

基板がケース内で上下左右の真ん中になるように位置を調整します。

ネジを固定します。  

取り外してしていたスイッチを取り付けます。

PCやMacに接続し、各部の動作を簡単に確認しておきます。

### プレートの取り付け

レイアウト・スタイルに合わせ、ミドルプレートとトッププレートを取り付けます。  

**アクリルプレートは割れたりヒビが入ったりしやすいので、丁寧に扱います。**

アクリルプレートに貼ってある保護用紙を剥がします。  
少し剥がしにくいですが、端の方を爪で軽く引っ掻くようにすると剥がれます。

スペーサーにプレートを乗せ、M2 6mmの低頭ネジで固定します。  
なお、強くネジ止めするとアクリルプレートが割れるため、軽く固定される程度にしておきます。

### 仕上げ

ケース底面に滑り止めのクッションパッドを貼り付けます。  
60% プラスチックケースに付属するパッドが貼り付け部分よりも大きい場合は、ハサミなどでカットして貼り付けます。

（オプション）ロータリーエンコーダのノブを取り付けます。  
トッププレートに擦れないよう、ノブの差し込み具合を調整します。

キーキャップを取り付けます。

完成です。

写真を撮影し、`#Unison_kbd` のタグをつけてツイートすると設計者が喜んだりします。  
[Twitter: #Unison_kbd](https://twitter.com/search?q=%23Unison_kbd)

### RemapまたはVIAによるキーマップの変更

”Terminalスタイル VIA対応ファームウェア”を書き込んでいる場合、[Remap](https://remap-keys.app/)や[VIA](https://caniusevia.com/)によるキーマップの変更がおこなえます。

#### Remap

WebHID API対応のブラウザ（Chromeなど）を使用し、[Remap](https://remap-keys.app/)にアクセスします。

`START REMAP YOUR KEYBOARD`をクリックし、`+ KEYBOARD`押して表示されるリストからUnisonを選択して`接続`します。  

キーボードのレイアウトが表示されたら、キーマップを変更します。  

#### VIA

以下の定義ファイルをダウンロードしておきます。

[unison.json](https://gist.github.com/jpskenn/f194c18c5e68a0969275be76204f4772)

VIAアプリを開き、`SETTINGS`タブで`Show Design tab`をONにします。

`DESIGN`タブで`Load Draft Definition`の`Load`ボタンを押し、先ほどダウンロードした定義ファイル、”unison.json"を開きます。

キーボードのレイアウトが表示されたら、`CONFIGURE`タブでキーマップを変更します。

#### キーボードをファームウェアの初期設定に戻す方法

上記のツールを使用してキーマップを変更した後、何らかの原因でキーマップがおかしくなってしまった場合は、以下の手順でファームウェアの初期設定に戻してください。  
この操作を行うと、キーマップをファームウェアの初期設定に戻すことができ、正常に入力できるようになります。  
なお、キーマップに加え、オーディオのON/OFF状態やLEDの点灯モードなどもファームウェアの初期設定に戻ります。

USBケーブルを抜きます。

キーボード左上のキーを押したまま、USBケーブルを差し込みます。

そのまま10秒ほど待ち、押していたキーを離します。

USBケーブルを抜きます。

もう一度USBケーブルを差し込むと、リセットされた状態でキーボードが認識されます。

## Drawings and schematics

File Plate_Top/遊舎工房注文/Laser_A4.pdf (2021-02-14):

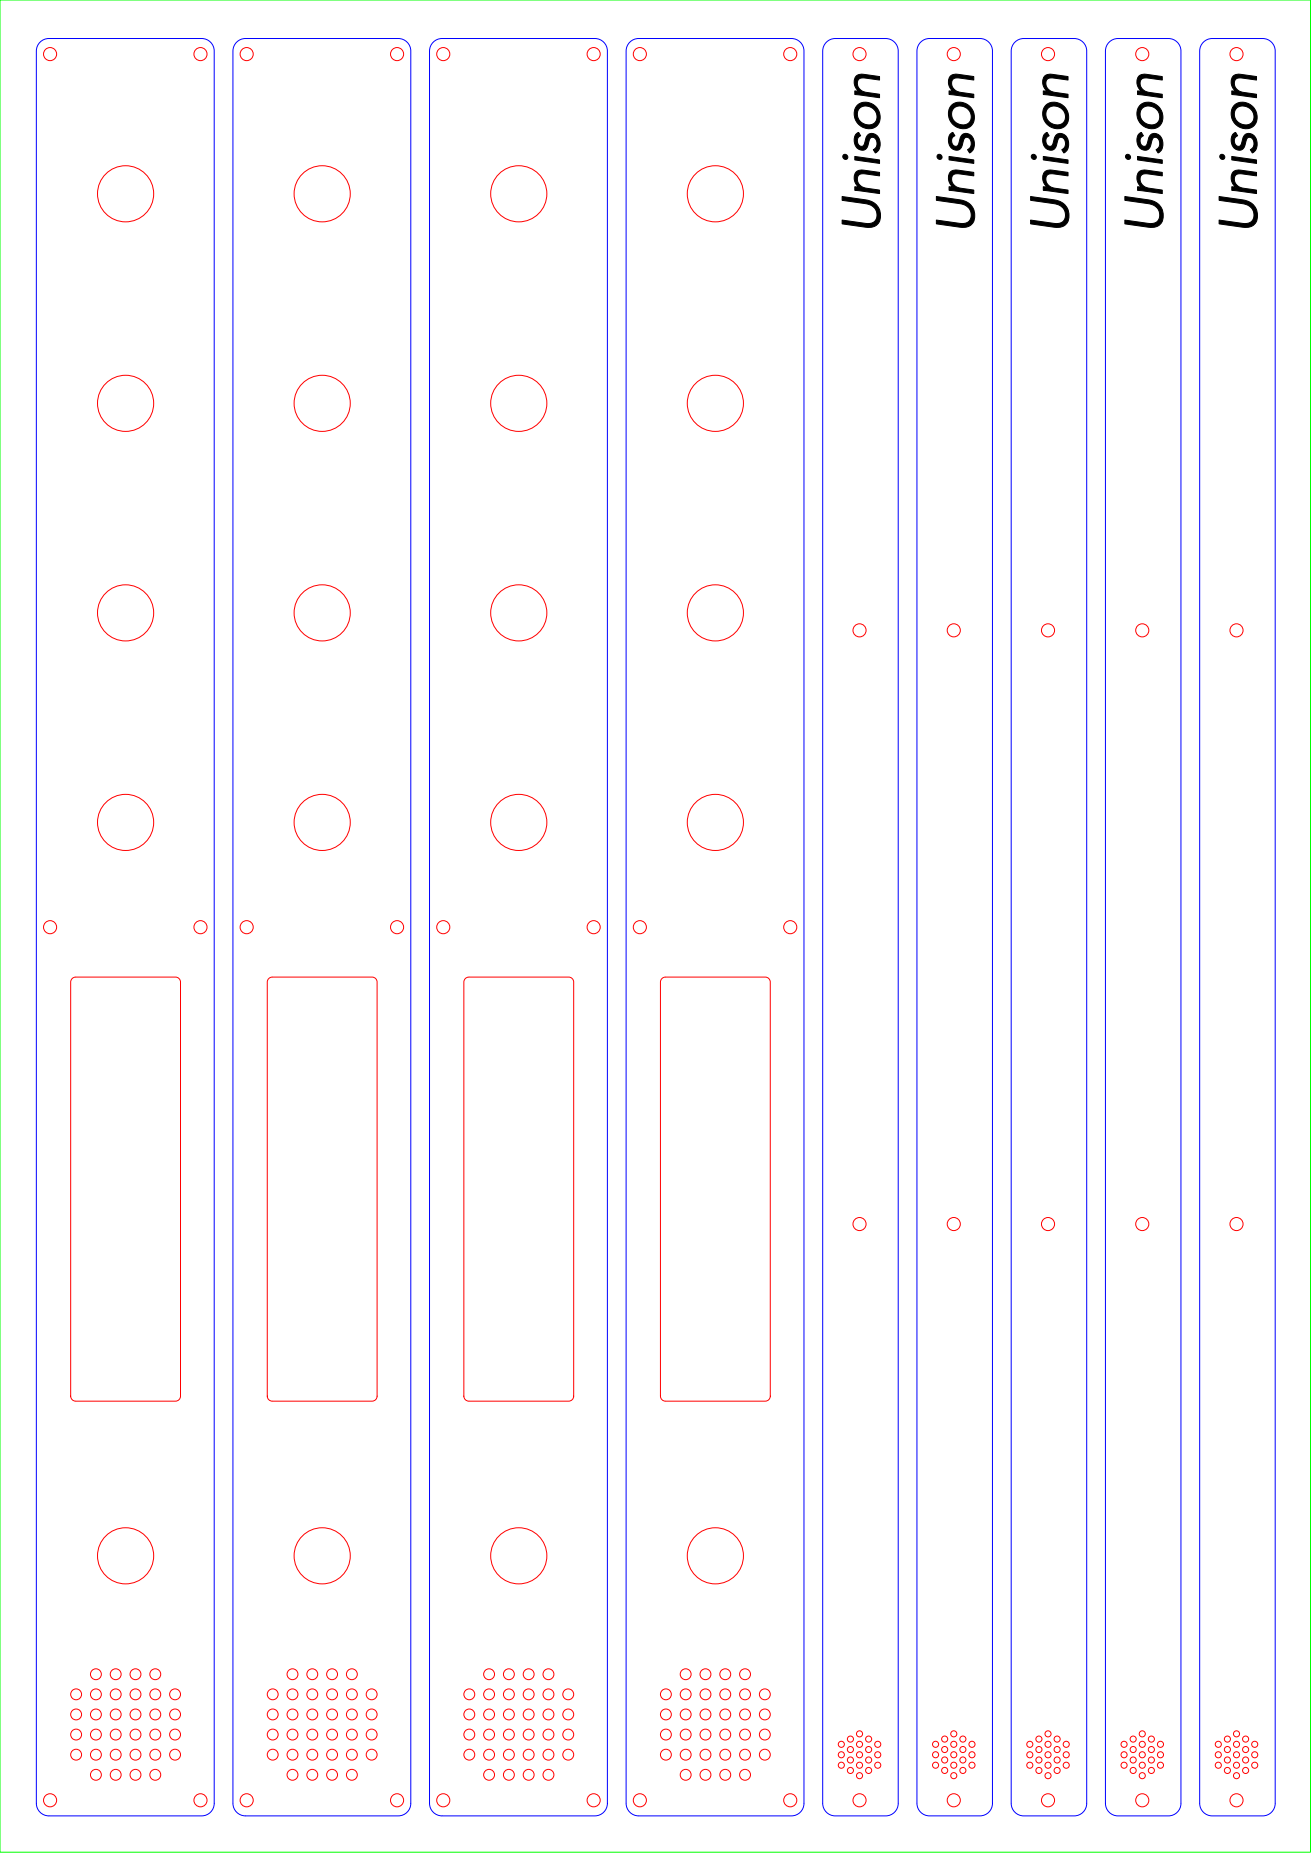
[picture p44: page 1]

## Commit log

2020-11-24 New メモ
    [雑多メモ.xlsx]
2020-12-20 New: Add memo.
    [雑多メモ.xlsx]
2020-12-20 Update: Jonesから回路図をインポート。ライブラリ追加。
    [Unison.kicad_pcb, Unison.sch]
2020-12-26 Update memo & layout test.
    [雑多メモ.xlsx]
2020-12-26 Update pcb.
    [Unison.sch]
2020-12-27 Update マトリクス
    [雑多メモ.xlsx]
2020-12-27 Update v01完成
    [Unison-B_Cu.gbl, Unison-B_Mask.gbs, Unison-B_Paste.gbp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]
2020-12-28 Update: Add screw holes between all OLED and Rotary Encoders.
    [Unison.kicad_pcb]
2020-12-28 Update: Change MCU from ATMega32u4-MU to ATMega32u4-AU.
    [Unison-B_Cu.gbl, Unison-B_Mask.gbs, Unison-B_Paste.gbp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]
2020-12-29 Update: MCUをMUからAUに変更し、配線をやり直した。
    [Unison.kicad_pcb, Unison.sch]
2020-12-29 Update: USBコネクタへの配線を変更し、配線長を短縮。その他配線の調整。
    [Unison.kicad_pcb]
2020-12-30 Update: バージョン表記が古いままだったので、v01_AUに変更。
    [Unison.kicad_pcb]
2021-01-06 Update: 配線削除。最下行がケースと干渉しないよう、0.5mmのクリアランスを追加。
    スイッチを0.5mm内側へ。（＝ケース外径を0.5ｍｍ下げた）
    [Unison.kicad_pcb]
2021-01-08 Update: ピンを11本使用した総当たりマトリクスの配置を追加。
    [雑多メモ.xlsx]
2021-01-08 Update: 11ピンを使用し、OP-1スタイルと、5行レイアウトのキーを配置。
    [Unison.sch]
2021-01-08 Update: 回路図：11ピンのマトリクスから10ピンに変更。
    OP-1レイアウト（4行＋最上段の1行）と5行レイアウトは排他のため、どちらも5行のマトリクスに収まる。
    [Unison.sch]
2021-01-09 Update: 回路図。LED個数、配線変更。スピーカージャンパ廃止。
    [Unison.sch]
2021-01-09 Update: PCB 部品配置、化粧板用ネジ穴追加。
    [Unison.kicad_pcb]
2021-01-09 Update: PCB シルク調整。部品位置調整。
    [Unison.kicad_pcb]
2021-01-09 Update: 溢れたはんだでショートしないよう、ダイオードとスイッチ穴の感覚に余裕を持たせる。
    [Unison.kicad_pcb]
2021-01-09 Update: PCB 5行レイアウト用にネジ穴を追加。OP-1レイアウトネジ穴位置調整。
    [Unison.kicad_pcb]
2021-01-09 Update: PCB 基板下側にネジ穴を追加。
    [Unison.kicad_pcb]
2021-01-09 Update: PCB、回路図。配線完了。
    [Unison.kicad_pcb, Unison.sch]
2021-01-10 Update: 回路図、PCB。ロータリーエンコーダをマウント穴付きのEC11Kタイプに対応。
    [Unison.kicad_pcb, Unison.sch]
2021-01-10 Update: PCB OP-1スタイルの最上段4キー部分で、左端の1キーが上へずれていたのを修正。
    [Unison.kicad_pcb]
2021-01-10 New: ミドルプレートの基本部分を追加。
    [Unison_Plate_Mid.kicad_pcb, Unison_Plate_Mid.sch]
2021-01-10 Update, Order: JLCPCBの注文番号の印字位置を指定し、ガーバー生成。発注。
    [Unison-B_Cu.gbl, Unison-B_Cu.gbr, Unison-B_Mask.gbr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]
2021-01-10 Update, Order: OP-1と5rowsのミドルプレートを作成し、ガーバー生成。発注。
    [Unison_Plate_Mid-B_Cu.gbr, Unison_Plate_Mid-B_Mask.gbr, Unison_Plate_Mid-B_Paste.gbr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]
2021-01-10 New トッププレートの元データを登録。
2021-01-14 Update: アクリルトッププレートを作成。
2021-01-19 Update: アクリルレーザーカットの注文データを作成。
2021-01-19 Update: ポテンションメータを追加。配線未完了。
    [Unison.kicad_pcb, Unison.sch]
2021-01-24 Update: 簡単な説明を追加
2021-01-27 Update: ダイオードの方向を統一
    [Unison.kicad_pcb]
2021-01-27 Update: 基板外形をネジ穴がNPTHのものへ変更。
    [Unison.kicad_pcb]
2021-01-27 Update: 右手親指Modに3キー追加。
    [Unison.kicad_pcb, Unison.sch]
2021-01-27 Update: OLED, ポテンションメーター廃止。ICSPと I2Cをピンヘッダで用意。
    [Unison.sch]
2021-01-27 Update: ICSP仮配置
    [Unison.kicad_pcb, Unison.sch]
2021-01-27 Update: 組立時、1uフットプリント兼用の2uキーの場所がわかりにくいため、2uフットプリントに変更し、シルクで判別できるようにした。
    [Unison.kicad_pcb, Unison.sch]
2021-01-28 Update: ネジ穴かぶるスイッチのフットプリントをMill-maxソケットが使用できるものへ変更。LED光線もれ防止追加。
    [Unison.kicad_pcb, Unison.sch]
2021-01-28 Update: ネジ穴かぶるスイッチのフットプリントをMill-maxソケットが使用できるものへ変更。LED光線もれ防止追加。
    ファイル追加忘れ
    [Unison.kicad_pcb, Unison.sch]
2021-01-28 OP-1スタイルで、4キー部分とミッドとトッププレートの間隔広げるに伴い、設置場所が狭くなるため、インジケータLEDを3個から2個に減らした。
    [Unison.kicad_pcb, Unison.sch]
2021-01-30 Update: AU版、ひととおり完成。
    [Unison.kicad_pcb, Unison.sch]
2021-01-31 Update: MUに入れ替え。各部調整。
    [Unison.kicad_pcb, Unison.sch]
2021-01-31 Delete: 5rowsはミドルプレートなし（＝トッププレートのみ）とするため、ミッドプレートを削除。
    [Unison_Plate_Mid-B_Cu.gbr, Unison_Plate_Mid-B_Mask.gbr, Unison_Plate_Mid-B_Paste.gbr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]
2021-01-31 Update: v04基板を元に、Eco1.Userレイヤーにプレート用データを作成。
    [Unison_Plate_Mid.kicad_pcb]
2021-01-31 Update: OP-1スタイルのミドルプレートをv04で作成。
    [Unison_Plate_Mid-B_Cu.gbr, Unison_Plate_Mid-B_Mask.gbr, Unison_Plate_Mid-B_Paste.gbr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]
2021-01-31 Update: OP-1スタイルのミドルプレートに、スピーカーホールを追加。
    [Unison_Plate_Mid-B_Cu.gbr, Unison_Plate_Mid-B_Mask.gbr, Unison_Plate_Mid-B_Paste.gbr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]
2021-01-31 Update: トッププレート用データ作成。
2021-01-31 Update: ボトムプレートの左右スリットを閉じてネジ穴に変更。シルク調整。
2021-01-31 Update: クリスタルを少し移動し、周りをグランドで囲うように変更。
    [Unison.kicad_pcb]
2021-02-01 Update: キーマップ作成メモを追加。
    [Unison_keymap.csv, Unison_keymap.xlsx]
2021-02-01 New: ボトムプレート作成。
    [Bottom_Plate_for_Jones_and_Unison-B_Cu.gbr, Bottom_Plate_for_Jones_and_Unison-B_Mask.gbr, Bottom_Plate_for_Jones_and_Unison-B_SilkS.gbr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]
2021-02-01 Delete: 古いファイルを削除
2021-02-01 Update: 発注用データ準備。F1, D102はSMTに含めない。
    [Unison-B_Cu.gbr, Unison-B_Mask.gbr, Unison-B_Paste.gbr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]
2021-02-07 遊舎工房への発注データ作成。
2021-02-12 デモビデオ追加
2021-02-12 ビデオの埋め込み失敗を修正
2021-02-12 文字によるリンクを追加
2021-02-12 動画であることを追記
2021-02-14 スタイル名など、最新の情報へ更新。
2021-02-17 特徴を大幅に加筆。
2021-02-17 製作歴を追加
2021-02-20 ビルドガイド初期作成
2021-02-21 ひとまず書きおわり
2021-02-21 細かな点を修正。ファームウェアHEXファイルは準備中。
2021-02-21 ギャラリーを追加。制作歴に追記。
2021-02-21 写真のリンクミス修正
2021-02-22 Windowsでの接続確認方法を修正
2021-02-22 VIA用定義ファイルを新規追加
2021-02-22 Terminalスタイル VIA対応ファームウェアをデフォルト書き込みとし、関連情報を追記。
2021-02-22 キーマップをdefaultファームウェアに合わせて若干変更。
2021-02-22 defautファームウェア向けのキーマップ図を追加。
2021-02-23 VIA用デフォルトレイアウト図を追加
2021-02-23 5pinスイッチ推奨について追記。
2021-02-23 ファームウェア関連の記述を更新。Terminalスタイルは、via対応ファームウェアの書き込みのみとする。
2021-02-23 キーマップ書きかえについて、完成後の手順とする。
2021-02-23 Audio機能の2音同時再生について、v04は未対応であることを追記。
2021-02-23 EEPROMを消去して、キーボードを初期設定に戻す方法を追記。
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2021-03-06 キャプションのミス修正
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
